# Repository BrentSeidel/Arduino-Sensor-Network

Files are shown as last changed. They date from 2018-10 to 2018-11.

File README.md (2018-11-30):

# Arduino Sensor Network
This repository contains software for a RS-485 based network of Arduinos reporting sensor
values.  A BeagleBone Black is connected to the RS-485 network and collects the data to
be presented was web pages.

Right now, the repository contains software and schematics/wiring diagrams.  It will be updated to also include
OpenSCAD models of parts for 3D printing, parts lists, and wiring diagrams.

## Contents
The contents are divided up into several directories as described below.

### Analyzer
This is Arduino software that just listens to the RS-485 bus and sends the contents back
to the host PC via USB.  It is occasionally useful when debugging to see what is really
on the RS-485 bus.

### Controller
This is Arduino software that polls the other Arduinos on the RS-485 bus.  There should be
only one of these on the bus.  There are provisions for it to accept some commands from
the BeagleBone Black via discrete inputs.

### Documentation
This contains some documentation for the system.

### Monitor
This is Arduino software for a device that listens to the RS-485 bus and displays output
on an LCD.  It is currently obsolete and not being updated.  It might be useful is some
projects.

### Responder
This is Arduino software for a device that listens to the RS-485 bus and responds with data
from sensors.  Currently a few I2C based sensors are supported.  Discrete and Analog input
can also be added.

### RS-485
This is an Arduino library that handles most of the RS-485 network protocol.  It is used
by all of the other Arduino software and needs to be placed in your Arduino library folder.

### Web
This is Ada code for the web server that runs on the BeagleBone Black.  It is uses my
Ada-Web-Server repository on GitHub.

### Schematics
This is a collection of schematics created using KiCAD that are intended to provide assistance
for wiring up various components.

## Dependancies
Some of the items in this repository depend on other repositories.  In particular:
* Web depends on Ada-Web-Server and BBS-Embed-Ada, both of which also depend on  BBS-Ada.

## License
This software is licensed under GPL V3.0.  Should you with to use it with a different
license, please contact the author.

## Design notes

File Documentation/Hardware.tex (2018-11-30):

%\documentclass[10pt, draft]{article}
\documentclass[10pt]{article}

\usepackage{fancyhdr}
\usepackage{multind}
\usepackage{pstricks}
\usepackage{graphicx}
\usepackage[yyyymmdd]{datetime}
\renewcommand{\dateseparator}{-}
\usepackage{geometry}
\geometry{letterpaper}
%
% Front Matter
%
\title{Arduino Sensor Network Documentation -- Hardware}
\author{Brent Seidel \\ Phoenix, AZ}
\date{ \today }
%========================================================
%%% BEGIN DOCUMENT
\begin{document}
\maketitle

\section{Synopsis}
This document contains descriptions of the hardware used in the Arduino Sensor Network.

\section{Network}
The network is based on the RS-485 standard.

\subsection{Topology}
The network uses a daisy-chained topology.  Each end of the chain should have a termination resistor of about 120$\Omega$.  One wire in the pair should have a pull up resistor to V$_{cc}$ and the other wire should have a pull down resistor to Gnd.  This is done at the controller node (see Figure \ref{fig:controller}).

\begin{figure}
  \centering
  
  \caption{Controller Unit}
  \label{fig:controller}
\end{figure}

\subsection{Cabling}
The network cabling uses CAT-5 cables due to its easy availability.  It is not quite optimum for RS-485, but works for this application.  If your application pushes the limits more, you may need another solution.

\subsection{Connectors}
The cables are terminated with DE-9 connectors.  Pins 4 and 8 are used for the bus.  The other pins are avaialble.  Each node has 2 connectors so that the nodes can be daisy chained together.  The cables have male connectors and the nodes have female connectors.  Note that it might be simpler to use RJ45 connectors in your application.

\subsection{Interfacing}
The RS-485 drivers are p/n SN65HVD1781P from Texas Instruments.  Others will probably work, however it may simplify things if the same driver chip is used in all nodes.  It may also help you to get a quantity discount.  Since RS-485 is a differential bus, the drivers have two outputs called `A' and `B' or `+' and `-'.  One side goes high while the other side goes low.  Unfortunately, the labeling isn't completely consistent.  If you use the same driver throughout, you can just make sure that all the `A' sides are connected together and all the `B' sides are connected together.  If you mix drivers, you may need to do a little experimenting to make sure that the proper sides are connected.

\subsection{Baud Rate}
Since there is not a lot of data to transfer, a high baud rate is not necessary.  A higher data rate will put more of a processing load on the nodes and leave less time for them to process their data.  This is a bigger factor for the basic Arduinos.  My application uses 115.2kbps and it seems to work.  An oscilloscope shows that the waveform isn't too distorted.  It also don't put too heavy of a load on the nodes for this particular application.  If more processing is needed in the nodes, a lower baud rate may be needed.

\subsection{Backchannel}
It was decided that it would be useful to be able to send commands from the HTTP gateway (BeagleBone Black) to the controller.  To accomplish this, the TX side of the serial port on the BeagleBone Black and the RX side of one of the extra serial ports on the Arduino Mega 2560 were used.  Since the RS-485 drivers were purchased in bulk, there were some available.  Using these took care of the level shifting (3.3V to 5V) and any needed isolation between the two boards.

\section{Nodes}
There are three basic types of nodes in the network.

\subsection{Responder}
The responder nodes are either Arduino Unos or Boarduinos (an Arduino clone from Adafruit, p/n 72).  See Figure \ref{fig:basic} for an example basic connection of an Arduino Uno to the RS-485 bus and a sensor.  The responder nodes need at least a single serial port and should have an I2C port for interfacing with sensors.  Since the software is for Arduinos, it would need to be ported for any other platform.

\begin{figure}
  \centering
  
  \caption{Basic Arduino Uno Responder Unit with BME280, CCS811, and TSL2561 Sensors}
  \label{fig:basic}
\end{figure}

\subsection{Controller}
The controller is an Arduino Mega 2560.  See Figure \ref{fig:controller} for an example controller node.  Note that the RS-485 interface on the controller contains the pull up and pull down resistors for the A and B wires.  The controller node needs at least two serial ports and possibly other interfaces if it is also to produce data.

\subsection{Web Gateway}
The optional web gateway is a specialized form of listener.  It is based on the BeagleBone Black microcontroller.  See Figure \ref{fig:gateway} for an example web gateway node.  The HTTP gateway needs a serial port and an ethernet port.  The software is written in Ada 2012 and is based on Linux.  Any platform that supports this and has the required ports will probably work.

\begin{figure}
  \centering
  
  \caption{Web Gateway Unit}
  \label{fig:gateway}
\end{figure}

\section{Sensors/Inputs}
The responder nodes can use the discrete I/O pins and the analog input pins.  Custom code is needed to produce the data on the bus.  Software is written for three different I2C based sensors:

\begin{itemize}
  \item BME280 (Adafruit p/n 2652) - This sensor provides calibrated temperature, barometric pressure, and humidity.
  \item TSL2651 (Adafruit p/n 439) - This is a digital light sensor that provides a reading of the light intensity.
  \item CCS811 (Adafruit p/n 3566) - This sensor provides uncalibrated CO$_2$ and Volatile Organic Compound readings.
\end{itemize}

\section{Outputs}
The responder nodes can use the discrete I/O pins as outputs.  Custom code will be needed to set the value of these discretes.  Note that \texttt{LED\_PIN} is by default configured as an output and is controlled by the LSB of the discrete word from the controller.  Software is also provided for the following I2C output device:

\begin{itemize}
  \item PCA9685 (Adafruit p/n 815) - This device is a 6 channel, 12 bit PWM controller.
\end{itemize}

\section{3D Printed Parts}
To be added once 3D models are added to repository.

\section{Miscellaneous}
In addition to the micro controllers, a few of other parts are needed.  The parts for the RS-485 network have already been mentioned.  The sensors needed depend on what you want to do.  Some other parts will be helpful.  A pack of 0.1'' female headers (Adafruit p/n 598) comes in handy when you want to be able to plug and unplug connections.  A set of ``perma-proto'' boads is handy for soldering up simple circuits.  These are also available from Adafruit in various sizes.  I mostly used 1/2 and 1/4 sizes.

\end{document}

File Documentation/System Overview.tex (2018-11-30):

\documentclass[10pt, openany, draft]{article}

\usepackage{fancyhdr}
\usepackage{multind}
\usepackage{pstricks}
\usepackage{graphicx}
\usepackage[yyyymmdd]{datetime}
\renewcommand{\dateseparator}{-}
\usepackage{geometry}
\geometry{letterpaper}
%
% Front Matter
%
\title{Arduino Sensor Network Documentation -- Overview}
\author{Brent Seidel \\ Phoenix, AZ}
\date{ \today }
%========================================================
%%% BEGIN DOCUMENT
\begin{document}
\maketitle
\section{Synopsis}
This document will contain descriptions of the various components of the Arduino Sensor Network.  First is a brief overview of the various components and then a discussion of the communication protocol used between them.  An example network is shown in Figure \ref{fig:Example}.

\begin{figure}
  \centering
  \input{Network}
  \caption{Example Sensor Network}
  \label{fig:Example}
\end{figure}

\section{Components}
The network consists of two required components plus optional components.  The required components are a single controller and one or more responders.  Listeners may optionally be added as they simply monitor the bus traffic and do not transmit.  A BeagleBone Black listener is used to present the data from the network on web pages.  Note that the component boundaries are a little fuzzy in that some components can perform functions from multiple categories.

\subsection{Controller}
The controller is responsible for the operation of the bus.  It sends a request command to each node on the bus and waits for a response.  It may also send data messages.  Typically requests are done in a round-robin fashion -- request node 1, request node 2, etc.  If a node does not respond within a timeout period, it is marked as missing and the next node is polled.

It would probably be possible to combine the controller functions and the web gateway listener function into a BeagleBone Black or other similar embedded computer.  However, keeping them separate allows the controller to be simpler and keep the network functioning even if the web gateway has problems.  So, if presenting data collected on a web page is the primary function of the network, go ahead and combine them.  If, however the primary function of the network is monitoring and controlling something, it would be better to keep the web gateway separate.

\subsection{Responder}
One or more responders may be attached to the bus.  Each responder can produce one or more addresses of data.  The first address (address 0) is used for node identification.  It contains the name and the number of addresses produced by the node.  Additional addresses are produced depending on the sensors attached to the node and the node configuration.

\subsection{Listener}
Any number of listeners may be added to the network.  These simply monitor the network traffic and usually present it in a different format.  A listener can also be used to perform actions based on certain data on the network, though it would probably be better to use a responder that can report back what it is doing.

The BeagleBone Black is used as one example of a listener that presents the data on a web page.  Another example listener is an Arduino that simply listens to the bus and copies the characters to the host computer for display.

\subsection{Web Gateway}
The web gateway is a specialized listener.  It collects data from the bus and presents it as web pages and XML formatted data.  It is uses the \texttt{Ada-Web-Server} repository as the web server.  The RS-485 listener interface is implemented as an Ada Task that receives and processes data from the bus.  The back channel is another Ada Task that is used to transmit commands to the controller.  The use of a task is intended to prevent multiple commands being transmitted simultaneously and getting garbled.

\section{Protocol}
\subsection{Physical Layer}
The physical layer is RS-485 twisted pair.  CAT-5 cable is used because I happen to have a bunch of CAT-5 available and it works.  One pair is used leaving the other pairs available for other uses such as power distribution.  The baud rate is set to 115.2kbps.  This can be changed depending on the application.  The only constraint is that all nodes agree on the baud rate.

\subsection{Node Organization}
Each node is given a unique node ID.  The controller node is given ID 0.  The message format allows 32 bits for the node ID though typically small numbers would be used.  Each node can produce a number of addresses of data.  Address 0 is used to provide node information.  The information includes the number of addresses that the node can produce and the node's name.

\subsection{Messages}
Two types of messages are defined: Requests which only come from the controller and request a specific address of data from a specific node, and Responses which are the data produced by a responder in response to a request.

To aid in debugging, the format of the messages is in ASCII text.  The type of message is indicated by the first character, `\texttt{\@}' for requests and `\texttt{\#}' for responses.  The first two elements in both types of messages is the device ID and the address separated by a forward slash, `\texttt{/}'.  The end of the message is a percent sign, `\texttt{\%}' followed by a (currently unimplemented) checksum and a CR-LF.

All of the numbers are 32 bit unsigned integers expressed in hexadecimal, with leading zeros optional.  

\subsubsection{Requests}
Requests should only be sent by the controller node.  The first character in a request message is an ampersand, `\texttt{\@}'.  This is followed by the device ID in hex, followed by a forward slash, `\texttt{/}'.  Then the address in hex.  The address is optionally followed by a command code and value, each preceded by an apmersand `\texttt{\&}'.  This is followed by a percent sign, `\texttt{\%}' and a currently unused checksum in hex.  The message is terminated by a CR-LF.

If a command code is not specified, the default command code of 0 for \texttt{CMD\_READ} is used.  The currently defined command codes are in Table \ref{tab:commands}.

\begin{table}
  \centering
  \begin{tabular}{c l l}
    \hline
    Value & Symbol & Meaning \\
    \hline
    0 & \texttt{CMD\_READ} & Read data from the specified address.\\
    1 & \texttt{CMD\_RESET} & Perform a software reset.\\
    2 & \texttt{CMD\_WRITE} & Perform an application specific write.\\
  \end{tabular}
  \caption{Defined Command Codes}
  \label{tab:commands}
\end{table}

A typical request looks something like, `\texttt{@00000001/00000000\%FF}'.  This requests address 0 from device 1.  Since leading zeros are optional, the same message can also be expressed as, `\texttt{@1/0\%FF}'.

\subsubsection{Responses}
Responses are sent in response to a request from the controller node.  The first character in a response message is an octathorpe, `\texttt{\#}'.  This is followed by the device ID in hex, the address in hex, and the message type in hex, separated by a forward slash, `\texttt{/}', and ended by an ampersand, `\texttt{\&}'.  This is followed by the data fields.  These are up to 32 32-bit hex numbers separated by apmersands, `\texttt{\&}' and terminated by a percent sign, `\texttt{\%}'.  This is followed by a currently unused checksum in hex.  The message is terminated by a CR-LF.

The format of the responses flexible and the number of data fields sent depends on the type of message.  It may even vary between messages of the same type.  A typical response looks something like \texttt{\#2/1/4\&0\&0\&1E690\&175C0F1\&C775\%FF}.  This is a response from device ID 2, address 1 with message type 4 (\texttt{MSG\_TYPE\_BME280})

If the controller has data to send, it can send a response message without sending a request, as the request can be considered to be implied.

\subsubsection{Message Types}
To make the response messages easier to decode, each message has a message type field.  This indicates what to do with the rest of the data in the message.  Not all messages are currently implemented and more will likely be added.  The various message types are in Table \ref{tab:messagetype}.  Some of the message types have a subtype.  In particular, discretes have the defined types as shown in Table \ref{tab:disctype}, with more likely to be added.  The analog values have the defined types as shown in Table \ref{tab:analogtype}, with more likely to be added.

\begin{table}
  \centering
  \begin{tabular}{r l l}
    \hline
    Value & Symbol & Meaning \\
    \hline
    0 & \texttt{MSG\_TYPE\_UNKNOWN} & Undefined or not present.\\
    1 & \texttt{MSG\_TYPE\_EMPTY} & Everything is OK, but no data to send \\
    2 & \texttt{MSG\_TYPE\_NAK} & Address not supported \\
    3 & \texttt{MSG\_TYPE\_INFO} & Address 0 information message \\
    4 & \texttt{MSG\_TYPE\_BME280} & BME280 sensor values \\
    5 & \texttt{MSG\_TYPE\_DISCRETE} & Discretes \\
    6 & \texttt{MSG\_TYPE\_ANALOG} & Analog values (not yet implemented) \\
    7 & \texttt{MSG\_TYPE\_VERSION} & Version/Software ID (not yet implemented) \\
    8 & \texttt{MSG\_TYPE\_CCS811} & CCS811 sensor values \\
    9 & \texttt{MSG\_TYPE\_TSL2561} & TSL2651 sensor values \\
    10 & \texttt{MSG\_TYPE\_PCA9685} & PCA9685 PWM Controller\\
  \end{tabular}
  \caption{Defined Message Types}
  \label{tab:messagetype}
\end{table}

\begin{table}
  \centering
  \begin{tabular}{c l l}
    \hline
    Value & Symbol & Meaning \\
    \hline
    0 & \texttt{DISCRETE\_UNKNOWN} & Unknown discretes.\\
    1 & \texttt{DISCRETE\_CMD} & Command discretes.\\
    2 & \texttt{DISCRETE\_MIXED} & Mixed discrete types.\\
    3 & \texttt{DISCRETE\_SWITCH} & Discretes from switches.\\
  \end{tabular}
  \caption{Defined Discrete Types}
  \label{tab:disctype}
\end{table}

\begin{table}
  \centering
  \begin{tabular}{c l l}
    \hline
    Value & Symbol & Meaning \\
    \hline
    0 & \texttt{ANALOG\_UNKNOWN} & Unknown analog types.\\
    32 & \texttt{ANALOG\_MIXED} & Mixed analog types.\\
    64 & \texttt{ANALOG\_POT} & Analog values from potentiometers.\\
  \end{tabular}
  \caption{Defined Analog Types}
  \label{tab:analogtype}
\end{table}

\subsection{Back-Channel Commands}
While the commands are human usable, they are designed for ease of parsing, not ease of use.  It is expected that higher level software will provide a wrapper for them.  At this point, they should be considered to be experimental and subject to change.  There are two groups of commands:
\begin{itemize}
  \item General commands tell the controller to do something that applies to all nodes on the network.  The specific general commands currently defined are:
  \begin{itemize}
    \item \texttt{!A} Tell all nodes to turn their indicator LED off.
    \item \texttt{!B} Tell all nodes to turn their indicator LED on.
    \item \texttt{!C} Tell all nodes to toggle their indicator LED.
    \item \texttt{!D} Tell all nodes to identify themselves.
  \end{itemize}
  \item Directed commands are sent to a specific node telling it to do something.  The currently defined directed commands are:
  \begin{itemize}
    \item \texttt{!R<node>,} Request node it node id of \texttt{<node>} to perform a software reset.
    \item \texttt{!S<cmd>,<node>,<arg>,} Send an arbitrary command, \texttt{<cmd>}, to node id \texttt{<node>}, with command arguments, \texttt{<arg>}.
  \end{itemize}
  Where all numbers are in hexidecimal.  Note that the trailing comma is required.
\end{itemize}

\section{Logging}
Data can be logged to files for later analysis.  Provisions exist for logging to be started and stopped and started on a global basis or by record type.  Starting global logging creates the files for the data and stopping global logging closes the files.  To log data, logging has to be started globally and logging of the desired data has to be enabled.  The data records generally supported for logging are:
\begin{itemize}
  \item Node information records
  \item BME280 Temperature, pressure, and humidity sensor
  \item CCS811 eCO$_2$ and TVOC (total volatile organic compounds) air quality sensor
  \item TLS2561 light sensor
\end{itemize}
The discretes and analogs are customized for the application and thus any logging of them would also have to be customized.  The existing logging code can be used as an example.  Note that logging can generate an enormous amount of data, so be prepared.
%======================================
\section{API}
A number of the defined URLs return XML information.  This can be used to create an API that can be used by programs beyond just a web browser.

%---------------------------------------------------------------
\subsection{Graphics}
Two of the URLs return an image in SVG format.  Typically, it is used for display on a web page, but could be used for other purposes.

%---------------------------------------------------------------
\subsubsection{Dial}
The URL is \texttt{/Dial}.  The parameters are:
\begin{itemize}
  \item \texttt{min} - Specify the minimum value shown on the dial (required).
  \item \texttt{max} - Specify the maximum value shown on the dial (required).
  \item \texttt{value} - Specify the value indicated by the dial's pointer (required).
\end{itemize}

%---------------------------------------------------------------
\subsubsection{Thermometer}
The URL is \texttt{/Thermometer}.  The parameters are:
\begin{itemize}
  \item \texttt{min} - Specify the minimum value shown on the thermometer (required).
  \item \texttt{max} - Specify the maximum value shown on the thermometer (required).
  \item \texttt{value} - Specify the value indicated by the thermometer (required).
\end{itemize}

%---------------------------------------------------------------
\subsection{Data and Control}
The rest of the URLs either return data or are used to control the system.  All of these return an XML message containing either requested data or an error message.

%---------------------------------------------------------------
\subsubsection{Send a Command to a Node}
This function is used to send a command to the controller via the back channel.  The URL is \texttt{/xml/Command}.  There is one parameter:
\begin{itemize}
  \item \texttt{command} - The command to send as text (required).
\end{itemize}

The returned data is returned in a \texttt{<xml>} block with the following contents:
\begin{itemize}
  \item \texttt{command} - Echoes the sent command, if the \texttt{command} parameter was present, or
  \item \texttt{error} - Provides an error message if the \texttt{command} parameter was not present.
\end{itemize}

%---------------------------------------------------------------
\subsubsection{Get System Counters}
The URL is \texttt{/xml/Counter}.  There are no parameters.  The returned data is in a \texttt{<xml>} block with the following contents:
\begin{itemize}
  \item \texttt{<counter>} - XML container for number of web requests handled counter.
  \item \texttt{<tasks>} - XML contained for number of currently active web handler tasks.
  \item \texttt{<rs485>} - XML container for RS-485 state machine activity counter.
\end{itemize}

%---------------------------------------------------------------
\subsubsection{Get Maximum Device Number on the Network}
The URL is \texttt{/xml/Devices}.  There are no parameters.  The returned data is in a \texttt{<xml>} block with the following contents:
\begin{itemize}
  \item \texttt{<length>} - XML container for the maximum device number found on the network.  Used to set the length of data structures.
\end{itemize}

%---------------------------------------------------------------
\subsubsection{Get Data from a Device on the Network}
While this call is simple, this returns the most complex set of data.  The URL is \texttt{/xml/DevData}.  There is one parameter:
\begin{itemize}
  \item \texttt{device} - Contains the node ID of the device to get data from (required).
\end{itemize}

The returned data is in an \texttt{<xml>} block.  The following components may, or may not be present depending on the configuration of the node:
\begin{itemize}
  \item \texttt{<info>} - This should always be present.
  \begin{itemize}
    \item \texttt{<validity>} - Validity status for info data.
    \item \texttt{<aging>} - Number of seconds since info message received.
    \item \texttt{<addresses>} - Number of addresses supported by device.
    \item \texttt{<name>} - Name of the node.
  \end{itemize}
  \item \texttt{<bme280>} - Present if node is configured with a BME280 sensor.
  \begin{itemize}
    \item \texttt{<validity>} - Validity status for BME280 data.
    \item \texttt{<aging>} - Number of seconds since BME280 message received.
    \item \texttt{<bme280\_status>} - Status of the BME280 sensor reported by node.
    \item \texttt{<bme280\_age>} - Number of frames since BME280 sensor data read.
    \item \texttt{<bme280\_temp\_c>} - Temperature in degrees Celcius.
    \item \texttt{<bme280\_pressure\_pa>} - Atmospheric pressure in Pascals.
    \item \texttt{<bme280\_humidity>} - Relative humidity in percent.
  \end{itemize}
  \item \texttt{<discretes>} - Present if node is configured to transmit discretes.
  \begin{itemize}
    \item \texttt{<validity>} - Validity status for discretes data.
    \item \texttt{<aging>} - Number of seconds since discretes message received.
    \item \texttt{<disc\_type>} - Code indicating the type of these discretes.
    \item \texttt{<disc\_value>} - Value of the discretes as a 32 bit unsigned integer.  One bit for each discrete.
  \end{itemize}
  \item \texttt{<analogs>} - Present if node is configured to transmit analog values.
  \begin{itemize}
    \item \texttt{<validity>} - Validity status for analog data.
    \item \texttt{<aging>} - Number of seconds since analog message received.
    \item \texttt{<analog\_type>} - Code indicating the type of these analog values.
    \item \texttt{<analog\_count>} - The number of analog value provided in this message.
    \item \texttt{<value>} - Value of analog reading.  This entry is repeated \texttt{analog\_count} times.  Once for each analog value.
  \end{itemize}
  \item \texttt{<ccs811>} - Present if node is configured with a CCS811 sensor.
  \begin{itemize}
    \item \texttt{<validity>} - Validity status for CCS811 data.
    \item \texttt{<aging>} - Number of seconds since CCS811 message received.
    \item \texttt{<ccs811\_status>} - Status of the CCS811 sensor reported by node.
    \item \texttt{<ccs811\_age>} - Number of frames since CCS811 sensor data read.
    \item \texttt{<ccs811\_eco2>} - Measurement of CO$_2$ concentration.
    \item \texttt{<ccs811\_tvoc>} - Measurement of total volatile organic compounds (TVOC) concentration.
  \end{itemize}
  \item \texttt{<tsl2561>} - Present if node is configured with a TSL2561 sensor.
  \begin{itemize}
    \item \texttt{<validity>} - Validity status for TSL2561 data.
    \item \texttt{<aging>} - Number of seconds since TSL2561 message received.
    \item \texttt{<tsl2561\_status>} - Status of the TSL2561 sensor reported by node.
    \item \texttt{<tsl2561\_age>} - Number of frames since TSL2561 sensor data read.
    \item \texttt{<tsl2561\_data0>} - Measurement of one band of light.
    \item \texttt{<tsl2561\_data1>} - Measurement of one band of light.
    \item \texttt{<tsl2561\_lux>} - Calculated illumination in Lux.
  \end{itemize}
  \item \texttt{<pca9685>} - Present if node is configured with a PCA9685 PWM controller.
  \begin{itemize}
    \item \texttt{<validity>} - Validity status for PCA9685 data.
    \item \texttt{<aging>} - Number of seconds since PCA9685 message received.
    \item \texttt{<channel>} - One of these entries for each of the 16 PWM channels.  Each entry contains three comma separated values.  The values are:
    \begin{itemize}
      \item A boolean indicating if this channel has been set.
      \item An unsigned integer indicating the PWM ``On'' count.
      \item An unsigned integer indicating the PWM ``Off'' count.
    \end{itemize}
  \end{itemize}
  \item \texttt{<error>} - Present if an error has occurred.
\end{itemize}

%---------------------------------------------------------------
\subsubsection{Control Debugging Messages}
Various debugging messages can be displayed on the console.  This entry can be used to turn messages on or off and to report the status of debugging messages.  The URL is \texttt{/xml/Debug}.  There are several parameters:
\begin{itemize}
  \item \texttt{rs485.char} - Set to `T' to print characters that are read from the RS-485 bus (optional).
  \item \texttt{rs485.msg} - Set to `T' to print the type of message that is read from the RS-485 bus (optional).
  \item \texttt{http.head} - Set to `T' to print the headers from each HTTP request (optional).
  \item \texttt{http.msg} - Set to `T' to print the HTTP requests (optional).
  \item \texttt{web.dbg} - Set to `T' to print debugging messages from the web server (optional).
\end{itemize}

The returned data is in a \texttt{<xml>} block with the following contents:
\begin{itemize}
  \item \texttt{<rs485.char>} - \texttt{TRUE} if RS-485 character debugging is enabled.
  \item \texttt{<rs485.msg>} - \texttt{TRUE} if RS-485 message debugging is enabled.
  \item \texttt{<http.head>} - \texttt{TRUE} if HTTP header debugging is enabled.
  \item \texttt{<http.msg>} - \texttt{TRUE} if HTTP request debugging is enabled.
  \item \texttt{<web.dbg>} - \texttt{TRUE} if web debugging is enabled.
\end{itemize}

%---------------------------------------------------------------
\subsubsection{Control Data Logging}
Starting logging is a two step process.  First the specific messages to log need to be enabled.  Then logging needs to be turned on.  The URL is \texttt{/xml/Log}.  There are several parameters:
\begin{itemize}
  \item \texttt{log.info} - Set to `T' to enable logging of info messages (optional).
  \item \texttt{log.BME280} - Set to `T' to enable logging of BME280 messages (optional).
  \item \texttt{log.CCS811} - Set to `T' to enable logging of CCS811 messages (optional).
  \item \texttt{log.TSL2561} - Set to `T' to enable logging of TSL2561 messages (optional).
  \item \texttt{logging} - Set to `T' to turn logging on (optional).
\end{itemize}

The returned data is in a \texttt{<xml>} block with the following contents:
\begin{itemize}
  \item \texttt{<log.info>} - \texttt{TRUE} if info message logging is enabled.
  \item \texttt{<log.BME280>} - \texttt{TRUE} if BME280 message logging is enabled.
  \item \texttt{<log.CCS811>} - \texttt{TRUE} if CCS811 message logging is enabled.
  \item \texttt{<log.TSL2561>} - \texttt{TRUE} if TSL2561 message logging is enabled.
  \item \texttt{<log.type>} - Set to the type of log files.  Currently either \texttt{NONE} or \texttt{CSV}.
\end{itemize}

%---------------------------------------------------------------
\subsubsection{Get Device Name}
The URL is \texttt{/xml/Name} name internal.  There is one parameter:
\begin{itemize}
  \item \texttt{device} - Specify the device number to get information from (required).
\end{itemize}

The returned data is in a \texttt{<xml>} block with the following contents:
\begin{itemize}
  \item \texttt{<info>} - Block containing device information, if present.  The information consists of the following:
  \begin{itemize}
    \item \texttt{<validity>} - Validity code for the data.
    \item \texttt{<aging>} - The time in seconds since the info record was received from the node.
    \item \texttt{<presence>} - The time in seconds since any records were received from the node.
    \item \texttt{<addresses>} - The number of addresses supported by the node.
    \item \texttt{<name>} - The node's name as a string.
  \end{itemize}
  \item \texttt{<error>} - Block containing an error message if device information cannot be provided.
\end{itemize}

\end{document}

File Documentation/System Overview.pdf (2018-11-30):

### Arduino Sensor Network Documentation – Overview

Brent Seidel
Phoenix, AZ

2018-11-25

## 1 Synopsis

This document will contain descriptions of the various components of the Arduino Sensor Network. First is a brief overview of the various components and then a discussion of the communication protocol used between them. An example network is shown in Figure 1.

## 2 Components

The network consists of two required components plus optional components. The required components are a single controller and one or more responders. Listeners may optionally be added as they simply monitor the bus traffic and do not transmit. A BeagleBone Black listener is used to present the data from the network on web pages. Note that the component boundaries are a little fuzzy in that some components can perform functions from multiple categories.

### 2.1 Controller

The controller is responsible for the operation of the bus. It sends a request command to each node on the bus and waits for a response. It may also send data messages. Typically requests are done in a round-robin fashion – request node 1, request node 2, etc. If a node does not respond within a timeout period, it is marked as missing and the next node is polled.
It would probably be possible to combine the controller functions and the web gateway listener function into a BeagleBone Black or other similar embedded computer. However, keeping them separate allows the controller to be simpler and keep the network functioning even if the web gateway has problems. So, if presenting data collected on a web page is the primary function of the network, go ahead and combine them. If, however the primary function of the network is monitoring and controlling something, it would be better to keep the web gateway separate.

### 2.2 Responder

One or more responders may be attached to the bus. Each responder can produce one or more addresses of data. The first address (address 0) is used for node identification. It contains the name and the number of addresses produced by the node. Additional addresses are produced depending on the sensors attached to the node and the node configuration.

1

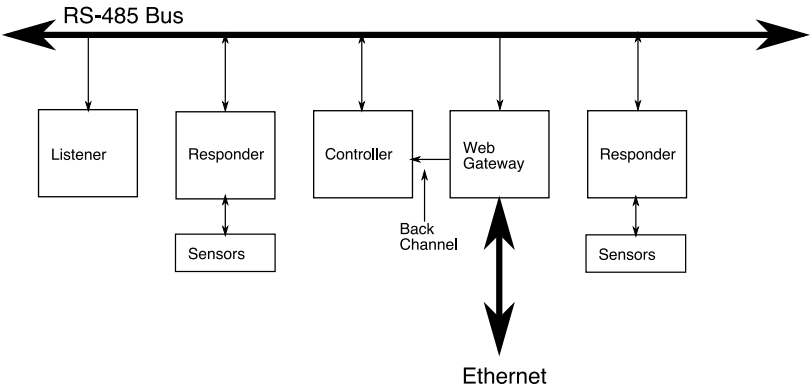
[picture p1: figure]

Figure 1: Example Sensor Network

### 2.3 Listener

Any number of listeners may be added to the network. These simply monitor the network traffic and usually present it in a different format. A listener can also be used to perform actions based on certain data on the network, though it would probably be better to use a responder that can report back what it is doing.
The BeagleBone Black is used as one example of a listener that presents the data on a web page. Another example listener is an Arduino that simply listens to the bus and copies the characters to the host computer for display.

### 2.4 Web Gateway

The web gateway is a specialized listener. It collects data from the bus and presents it as web pages and XML formatted data. It is uses the Ada-Web-Server repository as the web server. The RS-485 listener interface is implemented as an Ada Task that receives and processes data from the bus. The back channel is another Ada Task that is used to transmit commands to the controller. The use of a task is intended to prevent multiple commands being transmitted simultaneously and getting garbled.

## 3 Protocol

### 3.1 Physical Layer

The physical layer is RS-485 twisted pair. CAT-5 cable is used because I happen to have a bunch of CAT-5 available and it works. One pair is used leaving the other pairs available for other uses such as power distribution. The baud rate is set to 115.2kbps. This can be changed depending on the application. The only constraint is that all nodes agree on the baud rate.

2

Value Symbol | Meaning
0 | CMD READ | Read data from the specified address.
1 | CMD RESET | Perform a software reset.
2 | CMD WRITE | Perform an application specific write.

Table 1: Defined Command Codes

### 3.2 Node Organization

Each node is given a unique node ID. The controller node is given ID 0. The message format allows 32 bits for the node ID though typically small numbers would be used. Each node can produce a number of addresses of data. Address 0 is used to provide node information. The information includes the number of addresses that the node can produce and the node’s name.

### 3.3 Messages

Two types of messages are defined: Requests which only come from the controller and request a specific address of data from a specific node, and Responses which are the data produced by a responder in response to a request.
To aid in debugging, the format of the messages is in ASCII text. The type of message is indicated by the first character, ‘’ for requests and ‘#’ for responses. The first two elements in both types of messages is the device ID and the address separated by a forward slash, ‘/’. The end of the message is a percent sign, ‘%’ followed by a (currently unimplemented) checksum and a CR-LF. All of the numbers are 32 bit unsigned integers expressed in hexadecimal, with leading zeros optional.

### 3.3.1 Requests

Requests should only be sent by the controller node. The first character in a request message is an ampersand, ‘’. This is followed by the device ID in hex, followed by a forward slash, ‘/’. Then the address in hex. The address is optionally followed by a command code and value, each preceded by an apmersand ‘&’. This is followed by a percent sign, ‘%’ and a currently unused checksum in hex. The message is terminated by a CR-LF.
If a command code is not specified, the default command code of 0 for CMD READ is used. The currently defined command codes are in Table 1.
A typical request looks something like, ‘@00000001/00000000%FF’. This requests address 0 from device 1. Since leading zeros are optional, the same message can also be expressed as, ‘@1/0%FF’.

### 3.3.2 Responses

Responses are sent in response to a request from the controller node. The first character in a response message is an octathorpe, ‘#’. This is followed by the device ID in hex, the address in hex, and the message type in hex, separated by a forward slash, ‘/’, and ended by an ampersand, ‘&’. This is followed by the data fields. These are up to 32 32-bit hex numbers separated by apmersands, ‘&’ and terminated by a percent sign, ‘%’. This is followed by a currently unused checksum in hex. The message is terminated by a CR-LF.

3

Value Symbol | Meaning
0 MSG TYPE UNKNOWN | Undefined or not present.
1 MSG TYPE EMPTY | Everything is OK, but no data to send
2 MSG TYPE NAK | Address not supported
3 MSG TYPE INFO | Address 0 information message
4 MSG TYPE BME280 | BME280 sensor values
5 MSG TYPE DISCRETE | Discretes
6 MSG TYPE ANALOG | Analog values (not yet implemented)
7 MSG TYPE VERSION | Version/Software ID (not yet implemented)
8 MSG TYPE CCS811 | CCS811 sensor values
9 MSG TYPE TSL2561 | TSL2651 sensor values
10 MSG TYPE PCA9685 | PCA9685 PWM Controller

Table 2: Defined Message Types

Value Symbol | Meaning
0 | DISCRETE UNKNOWN | Unknown discretes.
1 | DISCRETE CMD | Command discretes.
2 | DISCRETE MIXED | Mixed discrete types.
3 | DISCRETE SWITCH | Discretes from switches.

Table 3: Defined Discrete Types

The format of the responses flexible and the number of data fields sent depends on the type of message. It may even vary between messages of the same type. A typical response looks something like #2/1/4&0&0&1E690&175C0F1&C775%FF. This is a response from device ID 2, address 1 with message type 4 (MSG TYPE BME280)
If the controller has data to send, it can send a response message without sending a request, as the request can be considered to be implied.

### 3.3.3 Message Types

To make the response messages easier to decode, each message has a message type field. This indicates what to do with the rest of the data in the message. Not all messages are currently implemented and more will likely be added. The various message types are in Table 2. Some of the message types have a subtype. In particular, discretes have the defined types as shown in Table 3, with more likely to be added. The analog values have the defined types as shown in Table 4, with more likely to be added.

Value Symbol | Meaning
0 | ANALOG UNKNOWN | Unknown analog types.
32 | ANALOG MIXED | Mixed analog types.
64 | ANALOG POT | Analog values from potentiometers.

Table 4: Defined Analog Types

4

### 3.4 Back-Channel Commands

While the commands are human usable, they are designed for ease of parsing, not ease of use. It is expected that higher level software will provide a wrapper for them. At this point, they should be considered to be experimental and subject to change. There are two groups of commands:

- General commands tell the controller to do something that applies to all nodes on the network. The specific general commands currently defined are:

– !A Tell all nodes to turn their indicator LED off.
– !B Tell all nodes to turn their indicator LED on.
– !C Tell all nodes to toggle their indicator LED.
– !D Tell all nodes to identify themselves.
- Directed commands are sent to a specific node telling it to do something. The currently defined directed commands are:

– !R<node>, Request node it node id of <node> to perform a software reset.
– !S<cmd>,<node>,<arg>, Send an arbitrary command, <cmd>, to node id <node>, with command arguments, <arg>.

Where all numbers are in hexidecimal. Note that the trailing comma is required.

## 4 Logging

Data can be logged to files for later analysis. Provisions exist for logging to be started and stopped and started on a global basis or by record type. Starting global logging creates the files for the data and stopping global logging closes the files. To log data, logging has to be started globally and logging of the desired data has to be enabled. The data records generally supported for logging are:

- Node information records
- BME280 Temperature, pressure, and humidity sensor
- CCS811 eCO2 and TVOC (total volatile organic compounds) air quality sensor
- TLS2561 light sensor

The discretes and analogs are customized for the application and thus any logging of them would also have to be customized. The existing logging code can be used as an example. Note that logging can generate an enormous amount of data, so be prepared.

## 5 API

A number of the defined URLs return XML information. This can be used to create an API that can be used by programs beyond just a web browser.

5

### 5.1 Graphics

Two of the URLs return an image in SVG format. Typically, it is used for display on a web page, but could be used for other purposes.

### 5.1.1 Dial

The URL is /Dial. The parameters are:

- min - Specify the minimum value shown on the dial (required).
- max - Specify the maximum value shown on the dial (required).
- value - Specify the value indicated by the dial’s pointer (required).

### 5.1.2 Thermometer

The URL is /Thermometer. The parameters are:

- min - Specify the minimum value shown on the thermometer (required).
- max - Specify the maximum value shown on the thermometer (required).
- value - Specify the value indicated by the thermometer (required).

### 5.2 Data and Control

The rest of the URLs either return data or are used to control the system. All of these return an XML message containing either requested data or an error message.

### 5.2.1 Send a Command to a Node

This function is used to send a command to the controller via the back channel. The URL is /xml/Command. There is one parameter:

- command - The command to send as text (required).

The returned data is returned in a <xml> block with the following contents:

- command - Echoes the sent command, if the command parameter was present, or
- error - Provides an error message if the command parameter was not present.

### 5.2.2 Get System Counters

The URL is /xml/Counter. There are no parameters. The returned data is in a <xml> block with the following contents:

- <counter> - XML container for number of web requests handled counter.
- <tasks> - XML contained for number of currently active web handler tasks.
- <rs485> - XML container for RS-485 state machine activity counter.

6

### 5.2.3 Get Maximum Device Number on the Network

The URL is /xml/Devices. There are no parameters. The returned data is in a <xml> block with the following contents:

- <length> - XML container for the maximum device number found on the network. Used to set the length of data structures.

### 5.2.4 Get Data from a Device on the Network

While this call is simple, this returns the most complex set of data. The URL is /xml/DevData. There is one parameter:

- device - Contains the node ID of the device to get data from (required).

The returned data is in an <xml> block. The following components may, or may not be present depending on the configuration of the node:

- <info> - This should always be present.

– <validity> - Validity status for info data.
– <aging> - Number of seconds since info message received. – <addresses> - Number of addresses supported by device. – <name> - Name of the node.
- <bme280> - Present if node is configured with a BME280 sensor.

– <validity> - Validity status for BME280 data.
– <aging> - Number of seconds since BME280 message received.
– <bme280 status> - Status of the BME280 sensor reported by node. – <bme280 age> - Number of frames since BME280 sensor data read. – <bme280 temp c> - Temperature in degrees Celcius.
– <bme280 pressure pa> - Atmospheric pressure in Pascals.
– <bme280 humidity> - Relative humidity in percent.
- <discretes> - Present if node is configured to transmit discretes.

– <validity> - Validity status for discretes data.
– <aging> - Number of seconds since discretes message received.
– <disc type> - Code indicating the type of these discretes.
– <disc value> - Value of the discretes as a 32 bit unsigned integer. One bit for each discrete.
- <analogs> - Present if node is configured to transmit analog values.

– <validity> - Validity status for analog data.
– <aging> - Number of seconds since analog message received.

7

– <analog type> - Code indicating the type of these analog values.
– <analog count> - The number of analog value provided in this message.
– <value> - Value of analog reading. This entry is repeated analog count times. Once for each analog value.
- <ccs811> - Present if node is configured with a CCS811 sensor.

– <validity> - Validity status for CCS811 data.
– <aging> - Number of seconds since CCS811 message received.
– <ccs811 status> - Status of the CCS811 sensor reported by node.
– <ccs811 age> - Number of frames since CCS811 sensor data read.
– <ccs811 eco2> - Measurement of CO2 concentration.
– <ccs811 tvoc> - Measurement of total volatile organic compounds (TVOC) concentration.
- <tsl2561> - Present if node is configured with a TSL2561 sensor.

– <validity> - Validity status for TSL2561 data.
– <aging> - Number of seconds since TSL2561 message received.
– <tsl2561 status> - Status of the TSL2561 sensor reported by node. – <tsl2561 age> - Number of frames since TSL2561 sensor data read. – <tsl2561 data0> - Measurement of one band of light.
– <tsl2561 data1> - Measurement of one band of light.
– <tsl2561 lux> - Calculated illumination in Lux.
- <pca9685> - Present if node is configured with a PCA9685 PWM controller.

– <validity> - Validity status for PCA9685 data.
– <aging> - Number of seconds since PCA9685 message received.
– <channel> - One of these entries for each of the 16 PWM channels. Each entry contains three comma separated values. The values are:
∗ A boolean indicating if this channel has been set.
∗ An unsigned integer indicating the PWM “On” count.
∗ An unsigned integer indicating the PWM “Off” count.
- <error> - Present if an error has occurred.

### 5.2.5 Control Debugging Messages

Various debugging messages can be displayed on the console. This entry can be used to turn messages on or off and to report the status of debugging messages. The URL is /xml/Debug. There are several parameters:

- rs485.char - Set to ‘T’ to print characters that are read from the RS-485 bus (optional).

8

- rs485.msg - Set to ‘T’ to print the type of message that is read from the RS-485 bus (optional).
- http.head - Set to ‘T’ to print the headers from each HTTP request (optional).
- http.msg - Set to ‘T’ to print the HTTP requests (optional).
- web.dbg - Set to ‘T’ to print debugging messages from the web server (optional).

The returned data is in a <xml> block with the following contents:

- <rs485.char> - TRUE if RS-485 character debugging is enabled.
- <rs485.msg> - TRUE if RS-485 message debugging is enabled.
- <http.head> - TRUE if HTTP header debugging is enabled.
- <http.msg> - TRUE if HTTP request debugging is enabled.
- <web.dbg> - TRUE if web debugging is enabled.

### 5.2.6 Control Data Logging

Starting logging is a two step process. First the specific messages to log need to be enabled. Then logging needs to be turned on. The URL is /xml/Log. There are several parameters:

- log.info - Set to ‘T’ to enable logging of info messages (optional).
- log.BME280 - Set to ‘T’ to enable logging of BME280 messages (optional).
- log.CCS811 - Set to ‘T’ to enable logging of CCS811 messages (optional).
- log.TSL2561 - Set to ‘T’ to enable logging of TSL2561 messages (optional).
- logging - Set to ‘T’ to turn logging on (optional).

The returned data is in a <xml> block with the following contents:

- <log.info> - TRUE if info message logging is enabled.
- <log.BME280> - TRUE if BME280 message logging is enabled.
- <log.CCS811> - TRUE if CCS811 message logging is enabled.
- <log.TSL2561> - TRUE if TSL2561 message logging is enabled.
- <log.type> - Set to the type of log files. Currently either NONE or CSV.

9

### 5.2.7 Get Device Name

The URL is /xml/Name name internal. There is one parameter:

- device - Specify the device number to get information from (required).

The returned data is in a <xml> block with the following contents:

- <info> - Block containing device information, if present. The information consists of the following:

– <validity> - Validity code for the data.
– <aging> - The time in seconds since the info record was received from the node.
– <presence> - The time in seconds since any records were received from the node. – <addresses> - The number of addresses supported by the node.
– <name> - The node’s name as a string.
- <error> - Block containing an error message if device information cannot be provided.

10

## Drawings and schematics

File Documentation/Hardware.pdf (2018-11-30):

# Arduino Sensor Network Documentation – Hardware

Brent Seidel
Phoenix, AZ

2018-11-26

## 1 Synopsis

This document contains descriptions of the hardware used in the Arduino Sensor Network.

## 2 Network

The network is based on the RS-485 standard.

### 2.1 Topology

The network uses a daisy-chained topology. Each end of the chain should have a termination resistor of about 120Ω. One wire in the pair should have a pull up resistor to Vcc and the other wire should have a pull down resistor to Gnd. This is done at the controller node (see Figure 1).

### 2.2 Cabling

The network cabling uses CAT-5 cables due to its easy availability. It is not quite optimum for RS-485, but works for this application. If your application pushes the limits more, you may need another solution.

### 2.3 Connectors

The cables are terminated with DE-9 connectors. Pins 4 and 8 are used for the bus. The other pins are avaialble. Each node has 2 connectors so that the nodes can be daisy chained together. The cables have male connectors and the nodes have female connectors. Note that it might be simpler to use RJ45 connectors in your application.

### 2.4 Interfacing

The RS-485 drivers are p/n SN65HVD1781P from Texas Instruments. Others will probably work, however it may simplify things if the same driver chip is used in all nodes. It may also help you to get a quantity discount. Since RS-485 is a differential bus, the drivers have two outputs called ‘A’ and ‘B’ or ‘+’ and ‘-’. One side goes high while the other side goes low. Unfortunately, the labeling isn’t completely consistent. If you use the same driver throughout, you can just make sure that all

1

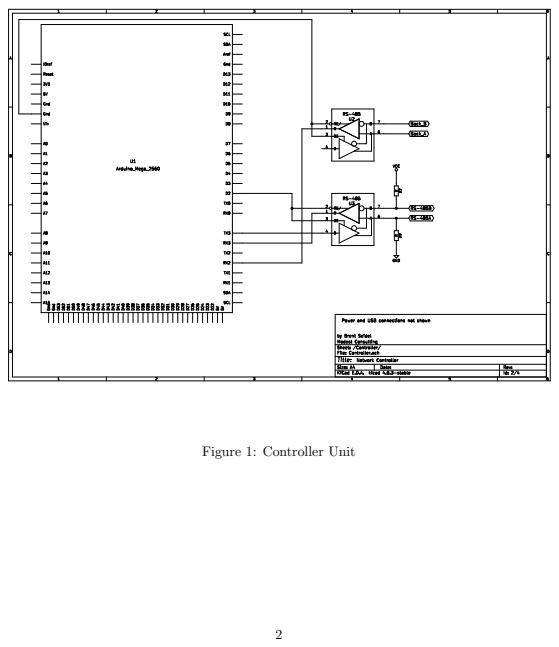
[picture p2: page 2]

Figure 1: Controller Unit

the ‘A’ sides are connected together and all the ‘B’ sides are connected together. If you mix drivers, you may need to do a little experimenting to make sure that the proper sides are connected.

### 2.5 Baud Rate

Since there is not a lot of data to transfer, a high baud rate is not necessary. A higher data rate will put more of a processing load on the nodes and leave less time for them to process their data. This is a bigger factor for the basic Arduinos. My application uses 115.2kbps and it seems to work. An oscilloscope shows that the waveform isn’t too distorted. It also don’t put too heavy of a load on the nodes for this particular application. If more processing is needed in the nodes, a lower baud rate may be needed.

### 2.6 Backchannel

It was decided that it would be useful to be able to send commands from the HTTP gateway (BeagleBone Black) to the controller. To accomplish this, the TX side of the serial port on the BeagleBone Black and the RX side of one of the extra serial ports on the Arduino Mega 2560 were used. Since the RS-485 drivers were purchased in bulk, there were some available. Using these took care of the level shifting (3.3V to 5V) and any needed isolation between the two boards.

## 3 Nodes

There are three basic types of nodes in the network.

### 3.1 Responder

The responder nodes are either Arduino Unos or Boarduinos (an Arduino clone from Adafruit, p/n 72). See Figure 2 for an example basic connection of an Arduino Uno to the RS-485 bus and a sensor. The responder nodes need at least a single serial port and should have an I2C port for interfacing with sensors. Since the software is for Arduinos, it would need to be ported for any other platform.

### 3.2 Controller

The controller is an Arduino Mega 2560. See Figure 1 for an example controller node. Note that the RS-485 interface on the controller contains the pull up and pull down resistors for the A and B wires. The controller node needs at least two serial ports and possibly other interfaces if it is also to produce data.

### 3.3 Web Gateway

The optional web gateway is a specialized form of listener. It is based on the BeagleBone Black microcontroller. See Figure 3 for an example web gateway node. The HTTP gateway needs a serial port and an ethernet port. The software is written in Ada 2012 and is based on Linux. Any platform that supports this and has the required ports will probably work.

3

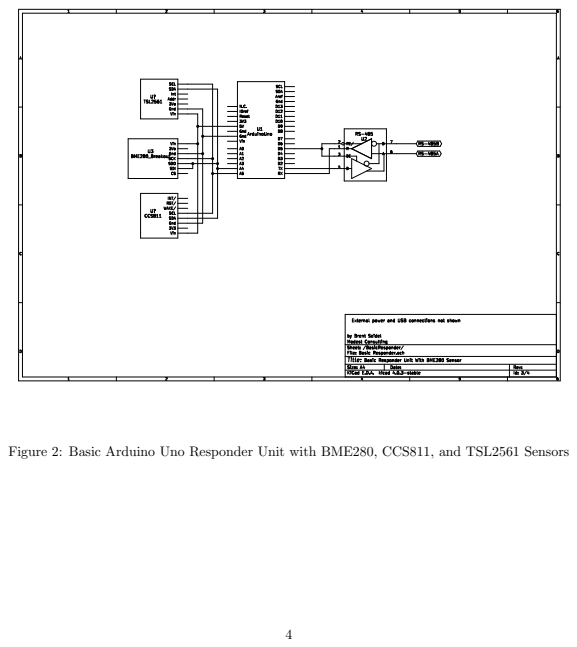
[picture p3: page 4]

Figure 2: Basic Arduino Uno Responder Unit with BME280, CCS811, and TSL2561 Sensors

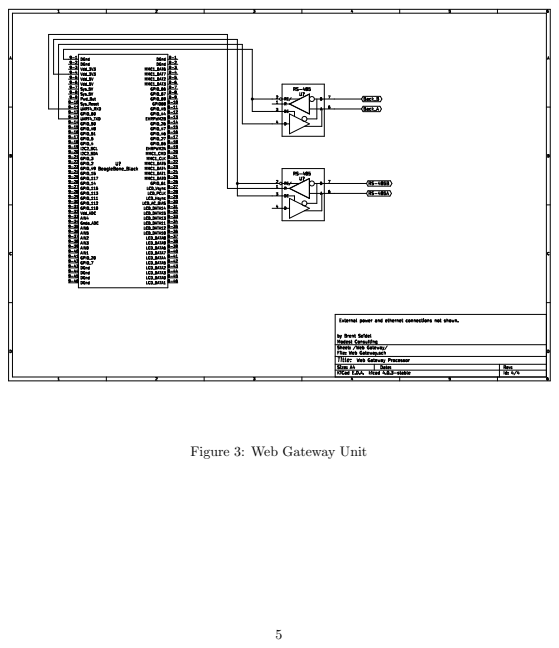
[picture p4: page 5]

Figure 3: Web Gateway Unit
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

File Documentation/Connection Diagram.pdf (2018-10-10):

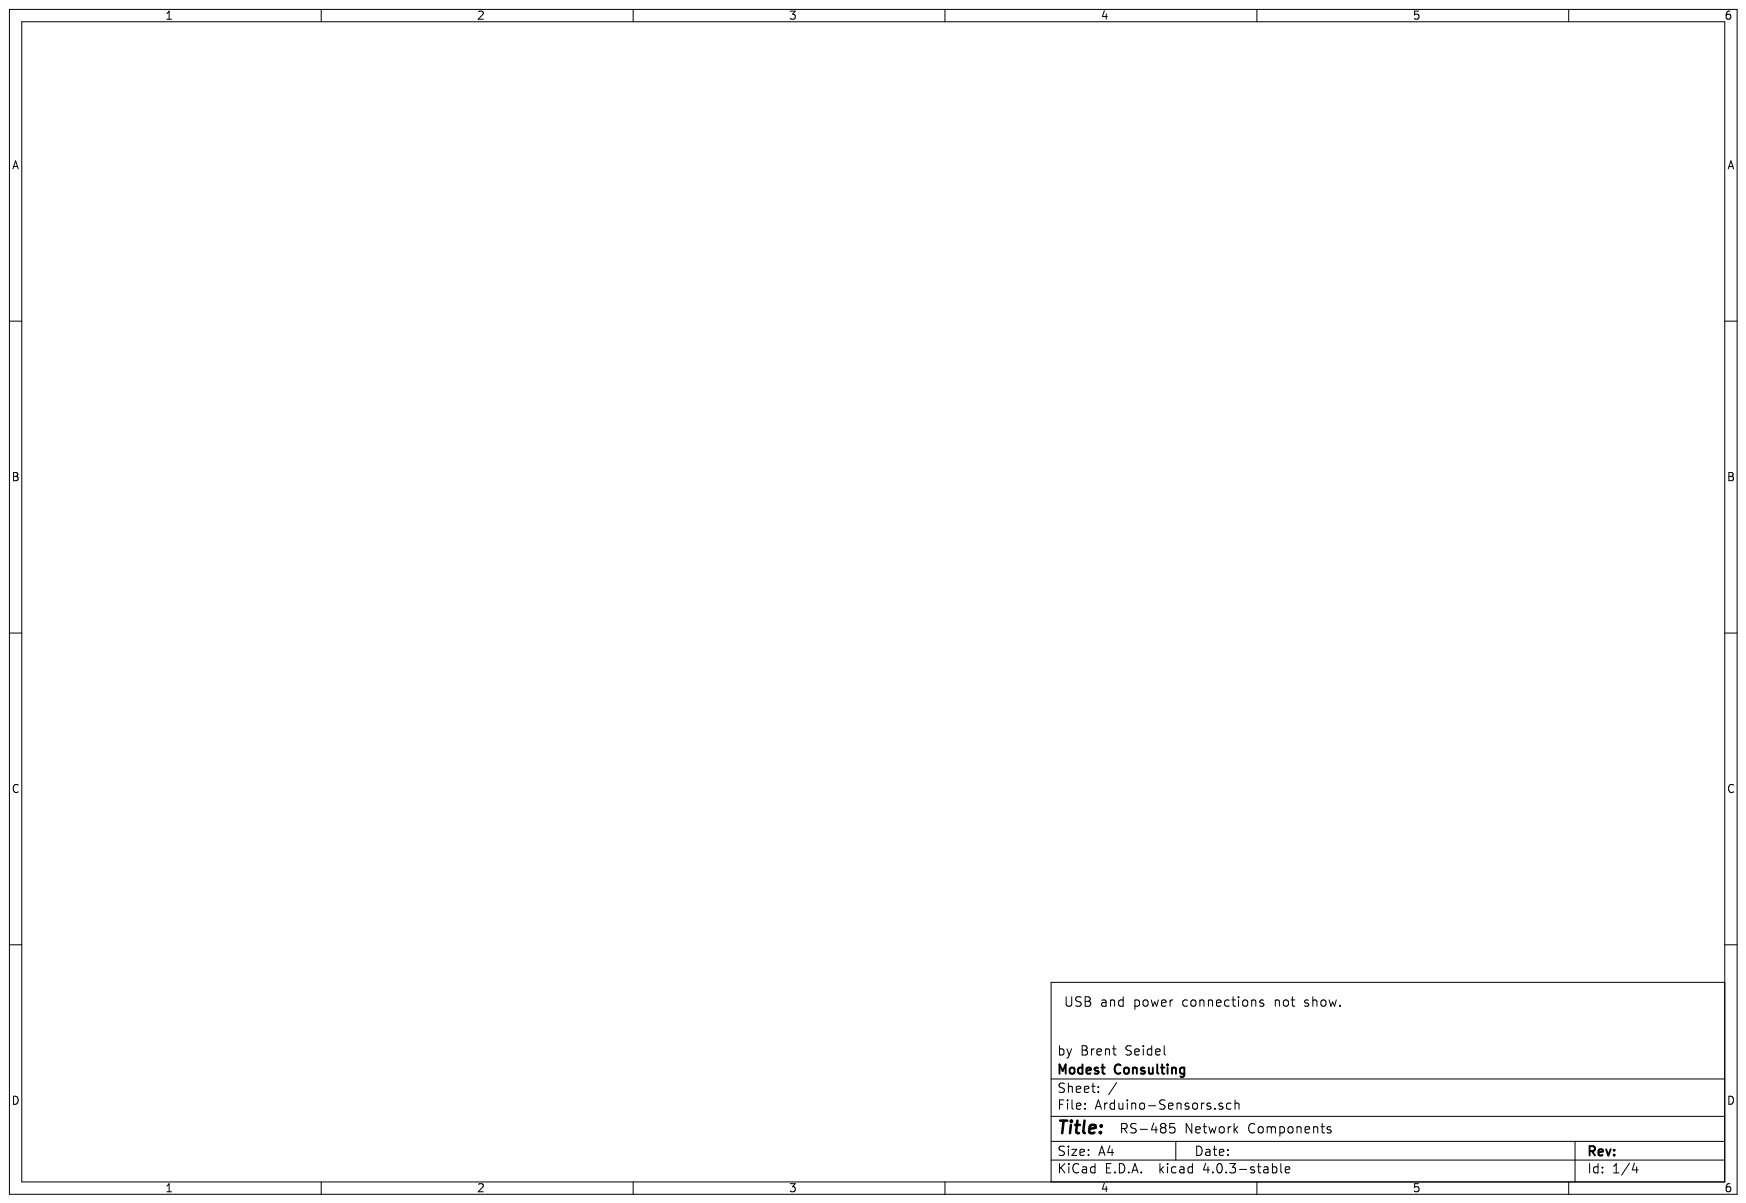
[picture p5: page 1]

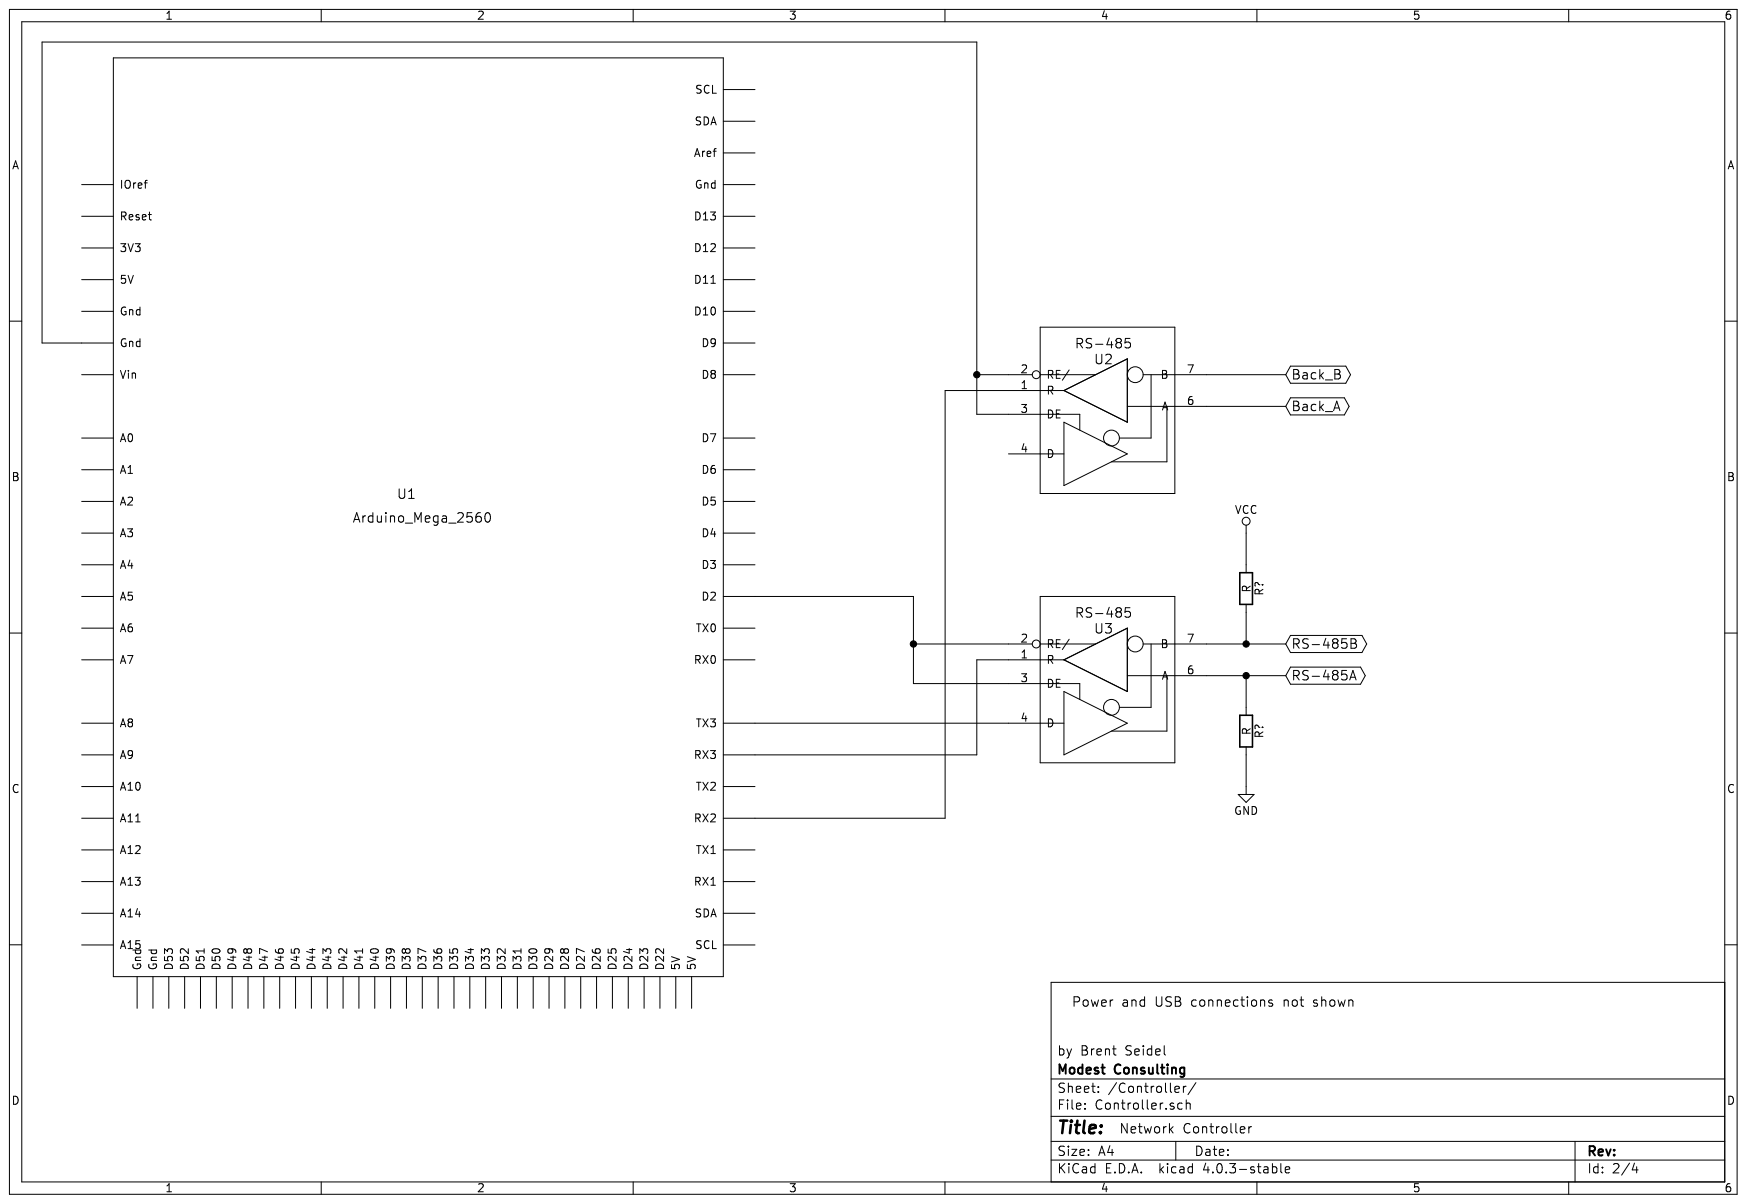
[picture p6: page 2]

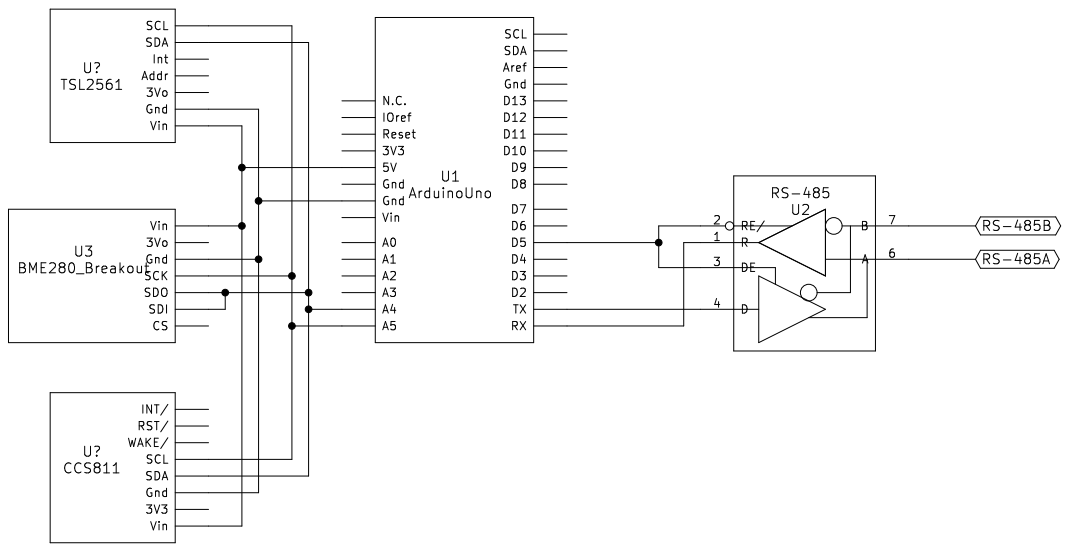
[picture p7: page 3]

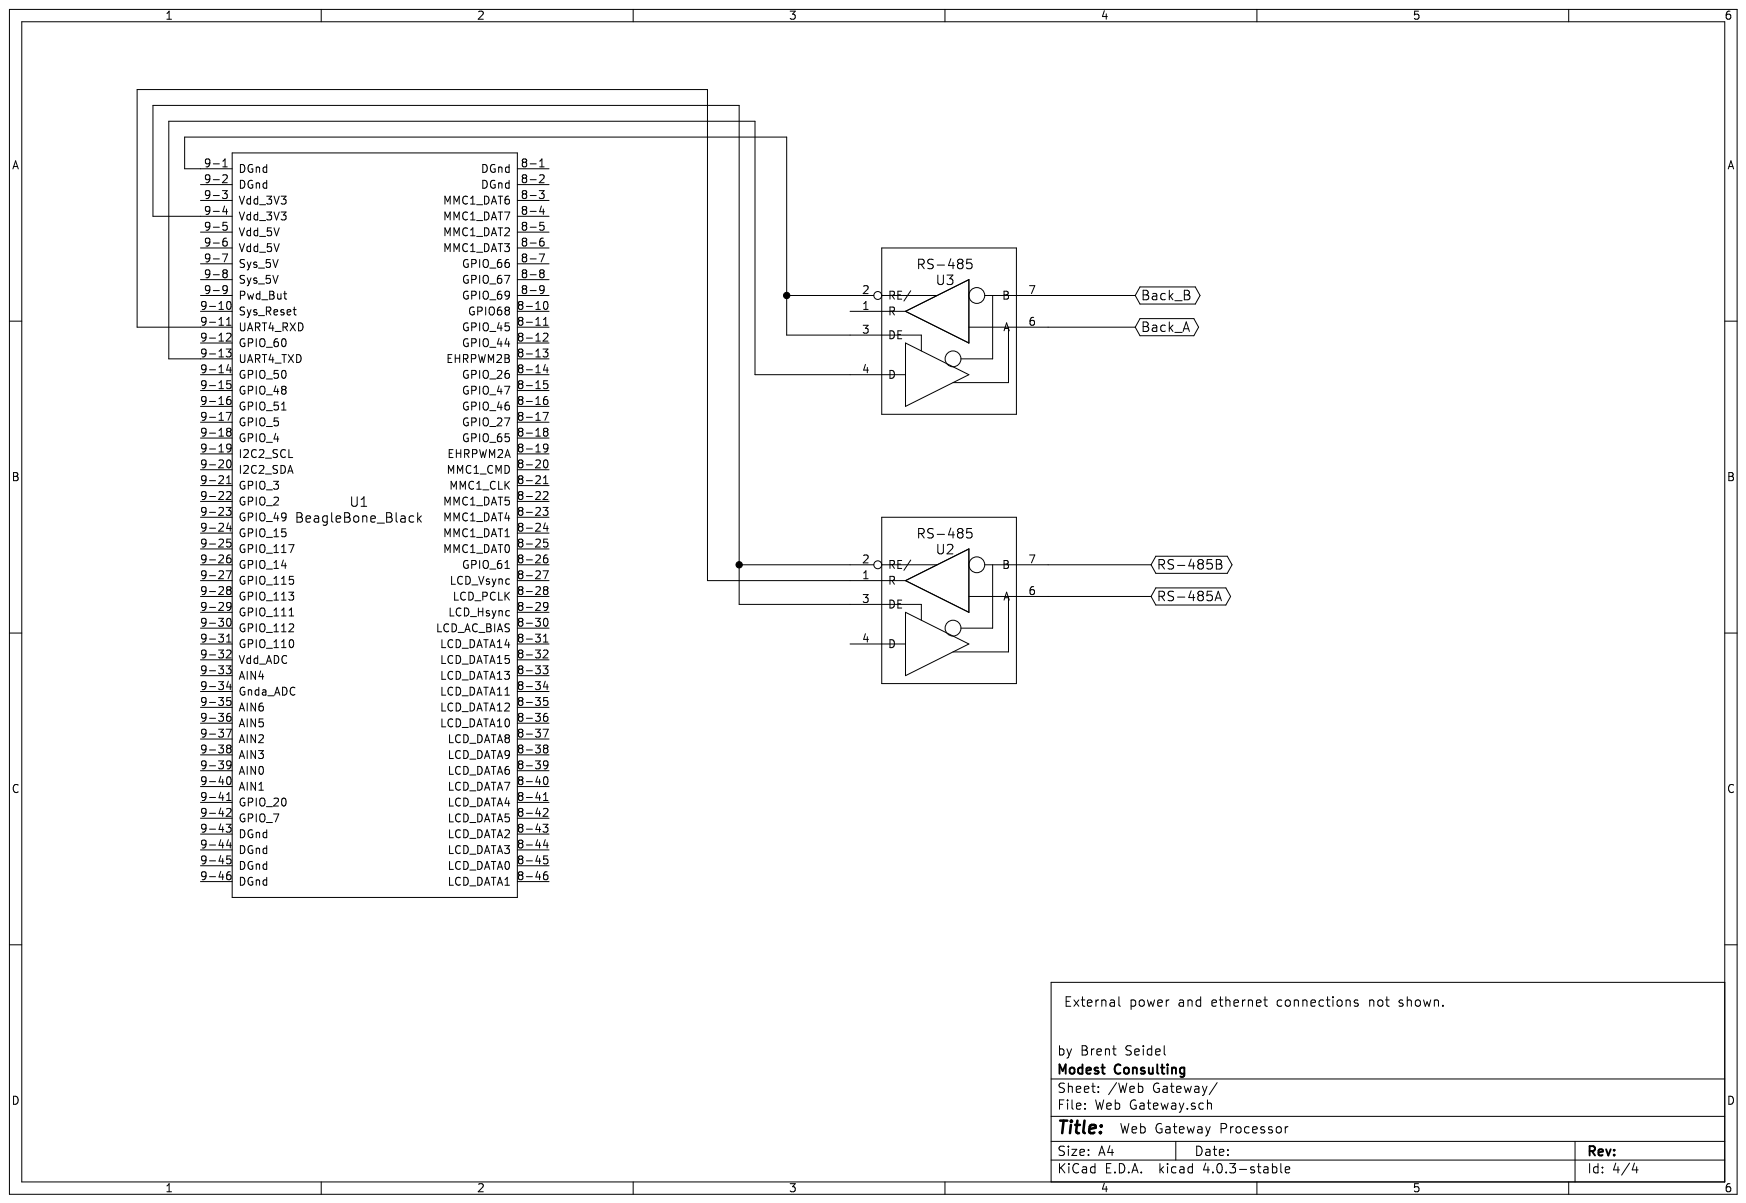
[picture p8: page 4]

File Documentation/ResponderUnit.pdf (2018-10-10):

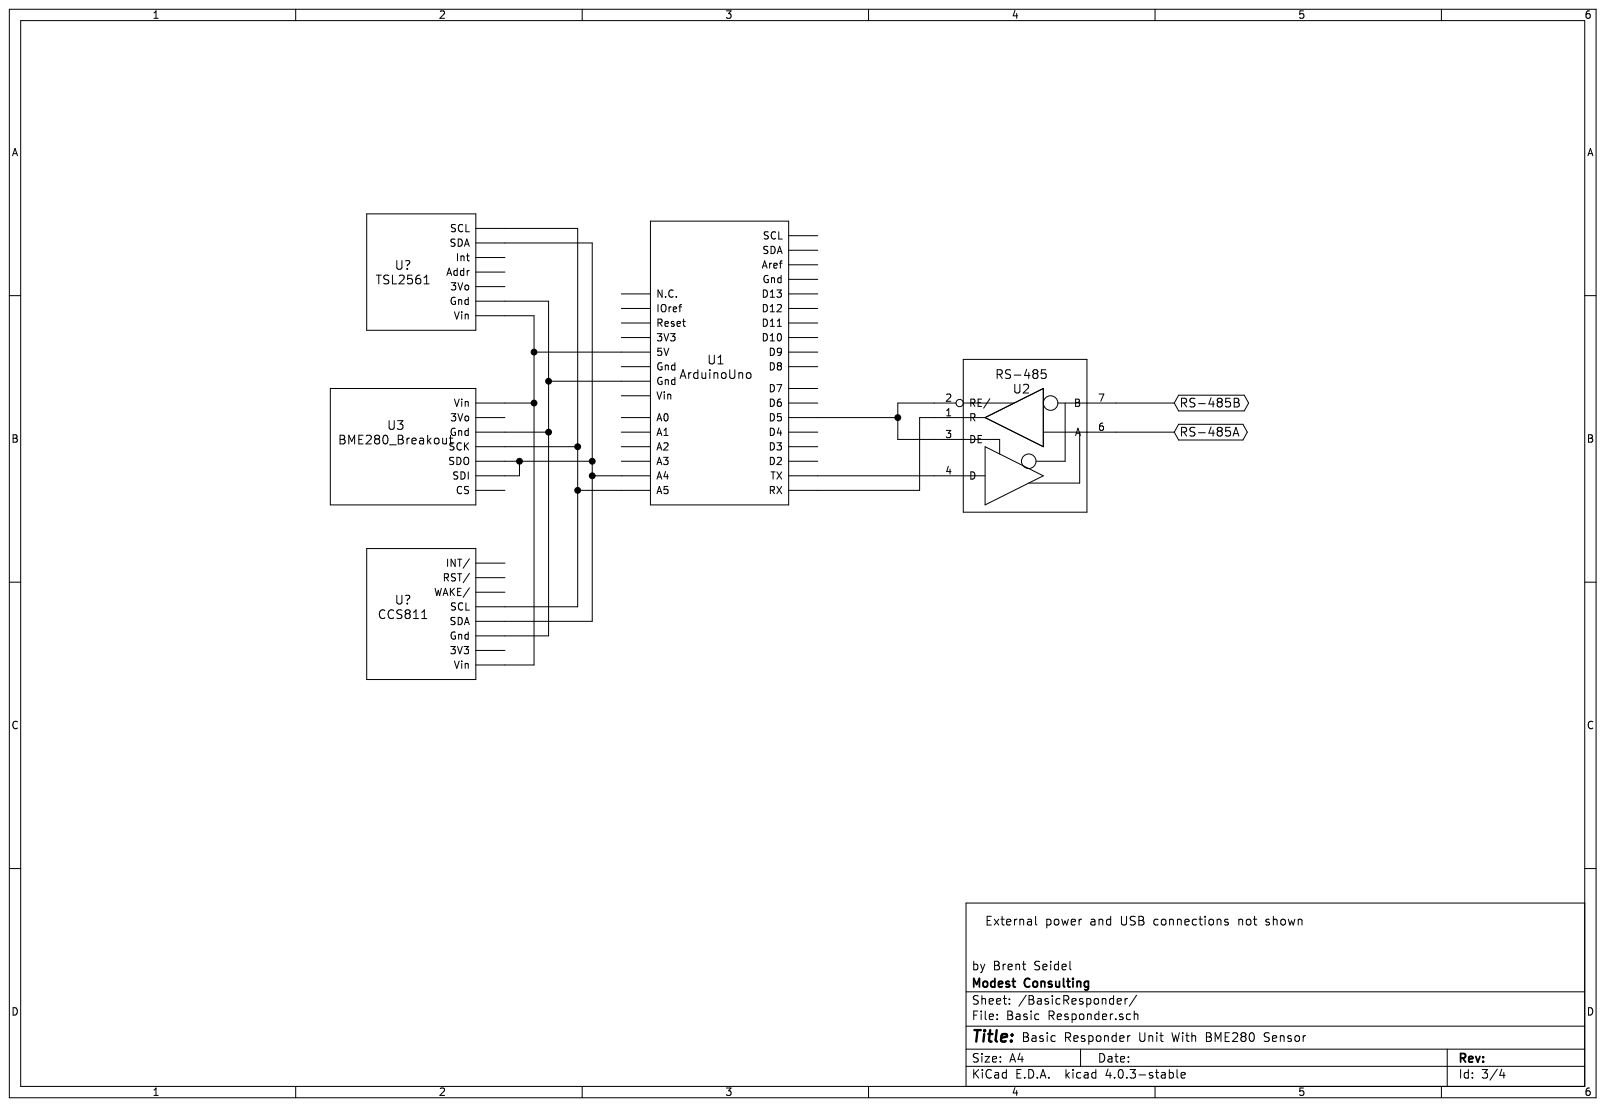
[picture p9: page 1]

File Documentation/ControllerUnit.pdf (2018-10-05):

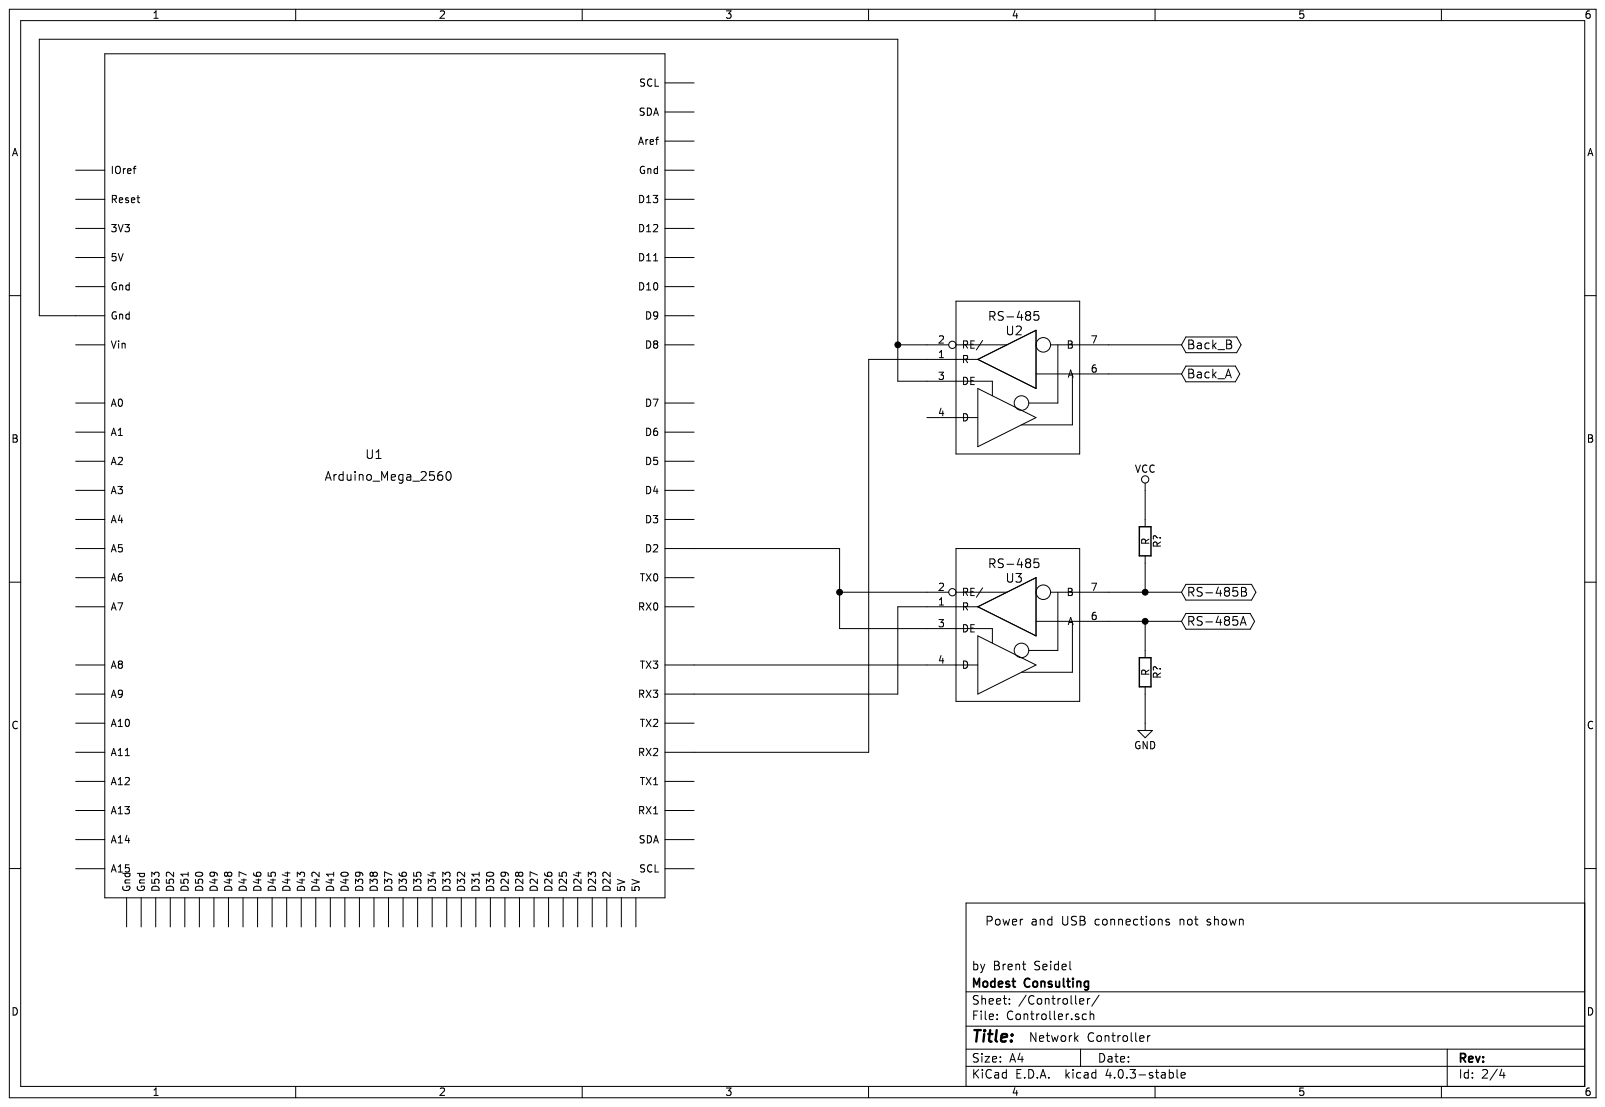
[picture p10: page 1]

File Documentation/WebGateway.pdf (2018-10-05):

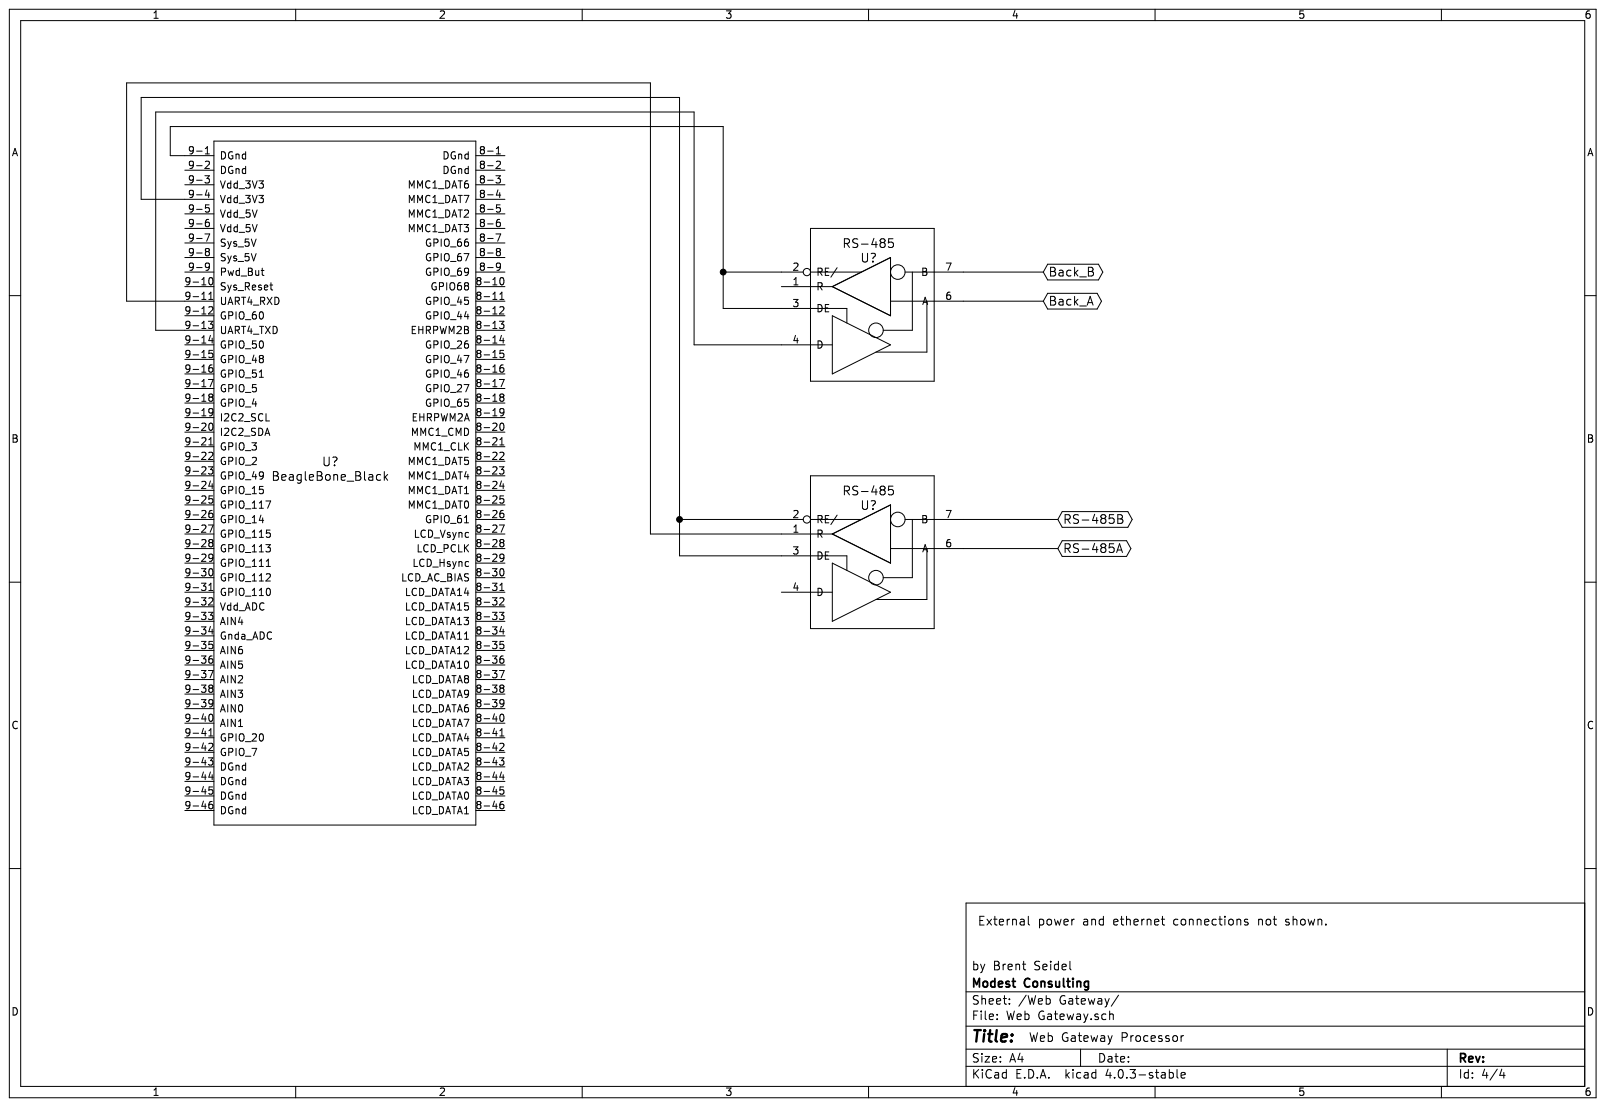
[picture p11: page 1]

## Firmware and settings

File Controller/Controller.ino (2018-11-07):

#include <RS-485.h>
//
// pin 7 - Switch input
// pin 6 - Switch input
// pin 5 - RS-485 direction output
//
//
// Change this to whichever port is hooked up to RS-485.  For the Uno, use the only
// serial port.  For the Mega and Due, use Serial3
//
// To allow commands from a BeagleBone Black, a Mega or Due is required.  In this case,
// the main RS-485 network is on Serial3 and the commands are input on Serial2.
//
#if defined (__AVR_ATmega328P__)
HardwareSerial *rs485 = &Serial;
#define RS485_TX_COMPLETE (SERIAL0_TX_COMPLETE)
#else
HardwareSerial *rs485 = &Serial3;
#define RS485_TX_COMPLETE (SERIAL3_TX_COMPLETE)
#endif
const int TX_RX = 2; // Pin 2 is used to control direction.
//
// The following two pins are used to generate signals that are useful for triggering
// an oscilloscope or other such device.
//
const int CMD_PIN = 23; // Set high while a command is being sent
const int MSG_PIN = 22; // Set high while a message is being sent
//
extern int get_hex_digit(int data);

//
// States
// 0 - Sending command
// 1 - Waiting for transmission to complete
// 2 - Waiting for '\r' indicating end of reply.
//
const uint8_t STATE_START = 0;
const uint8_t STATE_WAIT_TX = 12;
const uint8_t STATE_WAIT_RX = 13;
uint8_t state = STATE_START;
//
// Command definitions for general commands.  Directed commands are defined in the
// rs485.h header file.
//
const uint8_t CMD_NULL = 0;       // Do nothing special
const uint8_t CMD_LED_OFF = 1;    // Command all sensors to turn their LED off
const uint8_t CMD_LED_ON = 2;     // Command all sensors to turn their LED on
const uint8_t CMD_LED_TOGGLE = 3; // Command all sensors to toggle their LED (default case)
const uint8_t CMD_ID = 4;         // Request ID from all sensor units
//
//  Command states
//
const uint8_t CMD_STATE_START = 0;
const uint8_t CMD_STATE_CMD = 1;
const uint8_t CMD_STATE_GET_CMD = 2;
const uint8_t CMD_STATE_GET_NODE = 3;
const uint8_t CMD_STATE_GET_ARG = 4;
const uint8_t CMD_STATE_DONE = 5;
uint8_t read_cmd();
struct cmd_state_type
{
  uint8_t state;
  uint32_t cmd;
  uint32_t args;
  uint32_t node;
  boolean directed;
  boolean need_node;
  boolean need_cmd;
  boolean need_arg;
};
cmd_state_type cmd_data = {.state = CMD_STATE_START};
struct directed_cmd_type
{
  uint32_t cmd;
  uint32_t arg;
};
directed_cmd_type directed_cmd[NUM_NODES];
//
// Delays
//
#define XMIT_DELAY 1
#define TIMEOUT_DELAY 500
//
// Device ID and name
//
// Controller node ID (this node).  Controller is always node 0.
//
#define CTRL_NODE 0
//
// Name must be 32 characters padded with spaces on the end.
//                  12345678901234567890123456789012
const char* name = "Control, not KAOS               ";
//
uint32_t disc_value = 0;
//
// Supported number of nodes on network
//
int node_state[NUM_NODES];
int max_addr[NUM_NODES];
unsigned int max_node = 7;
unsigned int timeout_delay = TIMEOUT_DELAY;
unsigned long end_time;
unsigned int node_id = NUM_NODES;

const bool DEBUG = true;

void setup()
{
  int x;

  rs485->begin(BAUD_RATE);
  Serial2.begin(BAUD_RATE);
  Serial.begin(BAUD_RATE);
  pinMode(TX_RX, OUTPUT);  // RS-485 direction control
  pinMode(CMD_PIN, OUTPUT);
  pinMode(MSG_PIN, OUTPUT);
  for (x = 0; x < NUM_NODES; x++)
  {
    node_state[x] = 0;
    max_addr[x] = 0;
    directed_cmd[x].cmd = CMD_NULL;
    directed_cmd[x].arg = 0;
  }
}

void loop()
{
  int x;
  int data;
  uint8_t reply_state;
  uint8_t command;
  static uint8_t led_state = 0;
  static uint8_t led_command = CMD_LED_OFF;
//
// Process commands coming in on the discretes.
//
  switch (read_cmd())
  {
    case CMD_LED_OFF:
      led_command = CMD_LED_OFF;
      led_state = 0;
      break;
    case CMD_LED_ON:
      led_command = CMD_LED_ON;
      led_state = 1;
      break;
    case CMD_LED_TOGGLE:
      led_command = CMD_LED_TOGGLE;
      break;
    case CMD_ID:
      for (x = 0; x < NUM_NODES; x++)
      {
        node_state[x] = 0;
        max_addr[x] = 0;
      }
      break;
    default:
      break;
  }
//
// Main state machine
//
  switch (state)
  {
    case STATE_START:
      node_id++;
      if (node_id > max_node)
      {
        node_id = CTRL_NODE;
      }
      delay(XMIT_DELAY);
      if (node_id == CTRL_NODE)
      {
        Serial.println("Control node transmission");
      }
//      else
//      {
//        Serial.print("Requesting device ");
//        Serial.print(node_id, DEC);
//        Serial.print(" address ");
//        Serial.println(node_state[node_id]);
//      }
      digitalWrite(TX_RX, HIGH);  // Prepare to transmit
      if (node_id == CTRL_NODE)
      {
        digitalWrite(MSG_PIN, HIGH);
        if (node_state[CTRL_NODE] == 0)
        {
          rs485_msg_info(rs485, CTRL_NODE, 0, 1, name);
        }
        else
        {
          if (led_command == CMD_LED_TOGGLE)
          {
            led_state++;
            led_state = led_state % 2;
          }
          rs485_msg_disc(rs485, CTRL_NODE, 1, DISCRETE_CMD, disc_value*2 + led_state);
          //
          // For test purposes, just increment the discrete value.
          //
          disc_value++;
        }
        digitalWrite(MSG_PIN, LOW);
        node_state[CTRL_NODE] = 1;
      }
      else
      {
        if (directed_cmd[node_id].cmd == CMD_READ)
        {
//          Serial.print("Requesting read of node ");
//          Serial.println(node_id, DEC);
          digitalWrite(CMD_PIN, HIGH);
          rs485->print("@");
          rs485->print(node_id, HEX);
          rs485->print("/");
          rs485->print(node_state[node_id], HEX);
          rs485->println("%FF");
          digitalWrite(CMD_PIN, LOW);
        }
        else
        {
          Serial.print("Directed command to node ");
          Serial.println(node_id, DEC);
          digitalWrite(CMD_PIN, HIGH);
          rs485->print("@");
          rs485->print(node_id, HEX);
          rs485->print("/");
          rs485->print(node_state[node_id], HEX);
          rs485->print("&");
          rs485->print(directed_cmd[node_id].cmd, HEX);
          rs485->print("&");
          rs485->print(directed_cmd[node_id].arg, HEX);
          rs485->println("%FF");
          digitalWrite(CMD_PIN, LOW);
          directed_cmd[node_id].cmd = CMD_READ;
          directed_cmd[node_id].arg = 0;
        }
      }
      state = STATE_WAIT_TX;
      break;
    case STATE_WAIT_TX: // Wait for transmission to complete
      if (RS485_TX_COMPLETE)
      {
        digitalWrite(TX_RX, LOW);  // End transmission
        if (node_id == 0)
        {
          state = STATE_START; // There is no response to the message from the controller
        }
        else
        {
          state = STATE_WAIT_RX;
          end_time = millis() + TIMEOUT_DELAY; // Compute timeout value
        }
      }
      break;
    case STATE_WAIT_RX: // Wait for response or timemout
      reply_state = rs485_state_machine(rs485, &Serial, false);
      if (reply_state == STATE_RS485_GOT_MSG)
      {
//        Serial.print("Got reply from node ");
//        Serial.println(device, DEC);
        if (device == node_id)
        {
          if  (address == 0)
          {
            max_addr[node_id] = data_buffer[0];
          }
          node_state[node_id]++;
          if (node_state[node_id] > max_addr[node_id])
          {
            node_state[node_id] = 1;
          }
        }
        else
        {
          Serial.print("Node ");
          Serial.print(device, DEC);
          Serial.print(" responded, expected node ");
          Serial.println(node_id, DEC);
        }
        delay(5); // A little delay to wait for sender to release the bus
        state = STATE_START;
      }
      //
      // The timeout test here will need to be updated to account for wraparound
      // of the timer.
      //
      if (millis() > end_time)
      {
        node_state[node_id] = 0;
        state = STATE_START;
      }
      break;
    default:
      break;
  }
}
//
// This function processes commands received from the web gateway unit.  Two types of commands
// are available - general commands and directed commands.  General commands apply to all units
// on the network.  Directed commands are directed towards one particular node.
//
uint8_t read_cmd()
{
  int data = Serial2.read();
  uint8_t command = CMD_NULL;
  int     temp;

  if (data > 0)
  {
    switch (cmd_data.state)
    {
      case CMD_STATE_START:
        if (data == '!')
        {
          cmd_data.state = CMD_STATE_CMD;
        }
        cmd_data.cmd = CMD_NULL;
        cmd_data.args = 0;
        cmd_data.node = 0;
        cmd_data.directed = false;
        cmd_data.need_node = false;
        cmd_data.need_cmd = false;
        cmd_data.need_arg = false;
        break;
      case CMD_STATE_CMD:
        switch (data)
        {
          case 'A':
            Serial.println("Command LED Off");
            cmd_data.cmd = CMD_LED_OFF;
            cmd_data.state = CMD_STATE_DONE;
            break;
          case 'B':
            Serial.println("Command LED On");
            cmd_data.cmd = CMD_LED_ON;
            cmd_data.state = CMD_STATE_DONE;
            break;
          case 'C':
            Serial.println("Command LED Toggle");
            cmd_data.cmd = CMD_LED_TOGGLE;
            cmd_data.state = CMD_STATE_DONE;
            break;
          case 'D':
            Serial.println("Command Identify");
            cmd_data.cmd = CMD_ID;
            cmd_data.state = CMD_STATE_DONE;
            break;
          case 'R':
            Serial.println("Directed reset command");
            cmd_data.cmd = CMD_RESET;
            cmd_data.state = CMD_STATE_GET_NODE;
            cmd_data.directed = true;
            cmd_data.need_node = true;
            break;
          case 'S':
            Serial.println("Directed arbitrary command");
            cmd_data.state = CMD_STATE_GET_CMD;
            cmd_data.directed = true;
            cmd_data.need_node = true;
            cmd_data.need_arg = true;
            break;
          default:
            cmd_data.state = CMD_STATE_START;
            break;
        }
        break;
      case CMD_STATE_GET_CMD:
//        Serial.println("State get command.");
        temp = get_hex_digit(data);
        if (temp >= 0)
        {
          cmd_data.cmd = cmd_data.cmd*0x10 + temp;
        }
        else
        {
          if ((data == ',') && (cmd_data.need_node))
          {
            cmd_data.state = CMD_STATE_GET_NODE;
          }
          else if ((data == ',') && (cmd_data.need_arg)) 
          {
            cmd_data.state = CMD_STATE_GET_ARG;
          }
          else if (data == ',')
          {
            cmd_data.state = CMD_STATE_DONE;
          }
          else
          {
            cmd_data.state = CMD_STATE_START;
          }
        }
        break;
      case CMD_STATE_GET_NODE:
//        Serial.println("State get node.");
        temp = get_hex_digit(data);
        if (temp >= 0)
        {
          cmd_data.node = cmd_data.node*0x10 + temp;
        }
        else
        {
          if ((data == ',') && (cmd_data.need_arg)) 
          {
            cmd_data.state = CMD_STATE_GET_ARG;
          }
          else if (data == ',')
          {
            cmd_data.state = CMD_STATE_DONE;
          }
          else
          {
            cmd_data.state = CMD_STATE_START;
          }
        }
        break;
      case CMD_STATE_GET_ARG:
//        Serial.println("State get arg.");
        temp = get_hex_digit(data);
        if (temp >= 0)
        {
          cmd_data.args = cmd_data.args*0x10 + temp;
        }
        else
        {
          if (data == ',')
          {
            cmd_data.state = CMD_STATE_DONE;
          }
          else
          {
            cmd_data.state = CMD_STATE_START;
          }
        }
        break;
      case CMD_STATE_DONE:
//        Serial.println("State done.");
        cmd_data.state = CMD_STATE_START;
        if (cmd_data.directed)
        {
          Serial.print("Sending directed command ");
          Serial.print(cmd_data.cmd, DEC);
          Serial.print(" to node ");
          Serial.print(cmd_data.node, DEC);
          Serial.print(" with arguments ");
          Serial.println(cmd_data.args, DEC);
          if ((cmd_data.node > 0) && (cmd_data.node < NUM_NODES))
          {
            directed_cmd[cmd_data.node].cmd = cmd_data.cmd;
            directed_cmd[cmd_data.node].arg = cmd_data.args;
          }
        }
        else
        {
          command = cmd_data.cmd;
        }
        break;
      default:
        cmd_data.state = CMD_STATE_START;
        break;
    }
    Serial.write(data);
  }
  return command;
}

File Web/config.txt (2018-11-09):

#
# Configuration file for Ada web server
#
# HTML pages
#
/ index.html text/html
/Main index.html text/html
/Settings settings.html text/html
/Form form.html text/html
/Dashboard dashboard.html text/html
#
# Internal pages
#
/Config configure internal
/Form_Target target internal
/Thermometer thermometer internal
/Dial dial internal
/Devices devices internal
/ConfigReload reload internal
#
# Plain text
#
/list config.txt text/plain
/Proc/Status /proc/self/status text/plain
#
# JavaScript
#
/SetJS settings.js application/javascript
/DashJS dashboard.js application/javascript
#
# Images
#
# There are no images right now.
#
# XML stuff
#
/xml/Command send-command internal
/xml/Counter counter internal
/xml/Devices device-count internal
/xml/Name name internal
/xml/DevData device-data internal
/xml/Debug debugging internal
/xml/Log logging internal
#
# Style sheet for pages.
#
/Style table.css text/css
#
# Some comments at the end of the file.
#

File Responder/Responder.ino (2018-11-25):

#include <RS-485.h>
#include <Wire.h>
//
// Display debugging messages?  If set true, the node should either be an Arduino
// Mega 2560 (or similar with multiple serial ports) or disconnected from the network.
// On the basic Arduino the RS485 and the debug serial port are shared.
//
const bool DEBUG = false;
//
// Pick which serial device to use for the RS-485 interface.
//
#if defined (__AVR_ATmega328P__)
HardwareSerial *rs485 = &Serial;
#define RS485_TX_COMPLETE (SERIAL0_TX_COMPLETE)
#else
HardwareSerial *rs485 = &Serial3;
#define RS485_TX_COMPLETE (SERIAL3_TX_COMPLETE)
#endif
//
// System configuration.  This is used to enable or disable transmission of various
// messages depending on the nodes configuration.  In some cases (i.e. discretes or
// analogs), additional code will need to be added to process the inputs and produce
// the outputs.
//
// Configuration values.  These need to be set individually for each node.
//   name is a fixed lenght string giving the unit name
//   has_discretes set true if discrete values are transmitted
//   has_analogs set true if analog values are transmitted
//   num_analogs set to the number of analog values to transmit
//   has_sonar set to true if PING sonar unit is installed (currently unimplemented)
//
// Select the DEVICE_ID to build software for
//
#define DEVICE_ID 4
//
// Set fixed part of configuration based on the DEVICE_ID
//
// Name must be 32 characters padded with spaces on the end.
//                  12345678901234567890123456789012
#if DEVICE_ID == 1
  const char* name = "Bedroom Sensor Unit             "; // 1
  const bool has_discretes = false;
  const bool has_analogs = false;
  const uint8_t num_analogs = 0;
  const bool has_sonar = false;
#else
#if DEVICE_ID == 2
  const char* name = "Hall Monitor Unit               "; // 2
  const bool has_discretes = false;
  const bool has_analogs = false;
  const uint8_t num_analogs = 0;
  const bool has_sonar = false;
#else
#if DEVICE_ID == 3
  const char* name = "Office Sensor Unit              "; // 3
  const bool has_discretes = false;
  const bool has_analogs = false;
  const uint8_t num_analogs = 0;
  const bool has_sonar = false;
#else
#if DEVICE_ID == 4
  const char* name = "Development and Test Unit PWM   "; // 4
  const bool has_discretes = true;
  const bool has_analogs = true;
  const uint8_t num_analogs = 3;
  const bool has_sonar = false;
#else
#if DEVICE_ID == 5
  const char* name = "Guest Room Sensor Unit          "; // 5
  const bool has_discretes = false;
  const bool has_analogs = false;
  const uint8_t num_analogs = 0;
  const bool has_sonar = false;
#else
#if DEVICE_ID == 6
  const char* name = "Another Sensor Unit             "; // 6
  const bool has_discretes = false;
  const bool has_analogs = false;
  const uint8_t num_analogs = 0;
  const bool has_sonar = false;
#else
  const char* name = "Unknown Sensor Unit             "; // Other ID
  const bool has_discretes = false;
  const bool has_analogs = false;
  const uint8_t num_analogs = 0;
  const bool has_sonar = false;
#endif
#endif
#endif
#endif
#endif
#endif
//
// Check for the presence of I2C based sensors.  These are set during the I2C
// initialization.  Since these are autodetected, they do not need to be specified
// based on DEVICE_ID.
//
extern bool found_BME280;
extern bool found_TSL2561;
extern bool found_CCS811;
extern bool found_PCA9685;
//
// Configuration constants.  When this list gets updated, the determine_transmission
// and determine_config functions also needs to be updated.
//
const uint8_t CONFIG_NAK      = 0; // No configuration item
const uint8_t CONFIG_DISCRETE = 1; // Discretes item
const uint8_t CONFIG_ANALOG   = 2; // Analog item
const uint8_t CONFIG_BME280   = 3; // BME280 environment sensor
const uint8_t CONFIG_TSL2561  = 4; // TSL2561 light sensor
const uint8_t CONFIG_CCS811   = 5; // CCS811 air quality sensor
const uint8_t CONFIG_PCA9685  = 6; // PCA9685 16 channel 12 bit PWM controller

const uint8_t NUM_CONFIG = 7; // Number of configuration items
//
// Configuration array
//
uint8_t config_array[NUM_CONFIG];
//
// Build configuration array
//
uint8_t determine_config();
//
// Determine what to transmit
//
void determine_transmission(uint8_t value);
//
// This can be changed to whatever pin is being used.
//
const uint8_t TX_RX = 5; // Pin 5 is used to control direction.
//
// Routines to transmit I2C data
//
extern void send_BME280(HardwareSerial *);
extern void send_TSL2561(HardwareSerial *);
extern void send_CCS811(HardwareSerial *);
extern void send_PCA9685(HardwareSerial *);
//
extern uint8_t PCA9685_set_chan(uint8_t chan, uint16_t on, uint16_t off);

//
// Sample discrete value
//
uint32_t silly_counter = 0;
//
// Declare functions.
//
//
extern void i2c_init();
extern void i2c_state_machine();
//
// Do whatever local initialization is needed, then call the i2c initializatio
// function.  This will initialize the I2C bus and all the known devices on it.
//
void setup()
{
#if !defined (__AVR_ATmega328P__)
    Serial.begin(BAUD_RATE);
#endif
  rs485->begin(BAUD_RATE);
  if (DEBUG)
  {
    Serial.println(F("Starting initialization."));
    Serial.println(name);
  }
#if DEVICE_ID == 4
  analogReference(DEFAULT);
  pinMode(8, INPUT_PULLUP);
  pinMode(9, INPUT_PULLUP);
  pinMode(10, INPUT_PULLUP);
  pinMode(11, INPUT_PULLUP);
#endif
  pinMode(TX_RX, OUTPUT);
  pinMode(LED_BUILTIN, OUTPUT);
  digitalWrite(TX_RX, LOW);
  digitalWrite(LED_BUILTIN, LOW);
  i2c_init();
  if (DEBUG)
  {
    Serial.println(F("Initialization complete.  Waiting for data."));
  }
  determine_config();
}
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

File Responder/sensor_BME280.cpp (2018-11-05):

#include <RS-485.h>
#include <wiring_private.h>
#include <Wire.h>

static const bool DEBUG = false;
//
// I2C Stuff
//
const uint32_t I2C_TIMEOUT = 500;
extern uint8_t i2c_buffer[BUFFER_SIZE];
extern uint8_t buff_ptr;
extern uint8_t bytes_pending;
extern uint32_t end_time;
//
extern uint8_t i2c_start_read(uint8_t device, uint8_t reg, uint8_t bytes);
extern uint8_t i2c_read_pending();
//
extern bool found_BME280;
//
// Status for sub-state machines
//
static const uint8_t MACHINE_WORKING = 1;
static const uint8_t MACHINE_DONE = 2;
//
static const uint8_t STATE_BME280_START_CONVERSION = 1;
static const uint8_t STATE_BME280_ASK_DATA_READY = 2;
static const uint8_t STATE_BME280_CHECK_DATA_READY = 3;
static const uint8_t STATE_BME280_START_READ = 4;
static const uint8_t STATE_BME280_CHECK_READ = 5;
static const uint8_t STATE_BME280_END_READ = 6;
static const uint8_t STATE_BME280_PROCESS1 = 7;  // Split into three steps to avoid too much time in each loop
static const uint8_t STATE_BME280_PROCESS2 = 8;
static const uint8_t STATE_BME280_PROCESS3 = 9;
//
static uint8_t BME280_state = STATE_BME280_START_CONVERSION;
//
// Calibration values for BME280
//
static uint16_t BME280_cal_T1 = 0;
static int16_t BME280_cal_T2 = 0;
static int16_t BME280_cal_T3 = 0;
static uint16_t BME280_cal_P1 = 0;
static int16_t BME280_cal_P2 = 0;
static int16_t BME280_cal_P3 = 0;
static int16_t BME280_cal_P4 = 0;
static int16_t BME280_cal_P5 = 0;
static int16_t BME280_cal_P6 = 0;
static int16_t BME280_cal_P7 = 0;
static int16_t BME280_cal_P8 = 0;
static int16_t BME280_cal_P9 = 0;
static uint8_t BME280_cal_H1 = 0;
static int16_t BME280_cal_H2 = 0;
static uint8_t BME280_cal_H3 = 0;
static int16_t BME280_cal_H4 = 0;
static int16_t BME280_cal_H5 = 0;
static uint8_t BME280_cal_H6 = 0;
//
// Sensor values for BME280
//
static uint8_t BME280_status = DATA_INIT;
static uint8_t BME280_age = 0;
static uint32_t raw_press;
static uint32_t raw_temp;
static uint32_t raw_hum;
static int32_t  t_fine;    // Calibrated temperature
static uint32_t cal_press; // Calibrated pressure (Pa/256)
static uint32_t cal_hum;   // Calibrated humidity (%/1024)
//
// BME280 Constant values
//
static const uint8_t ADDR_BME280 = 0x77;
//
// Registers
//
static const uint8_t BME280_CTRL_HUM = 0xF2;
static const uint8_t BME280_STATUS = 0xF3;
static const uint8_t BME280_CTRL_MEAS = 0xF4;
static const uint8_t BME280_CONFIG = 0xF5;
static const uint8_t BME280_DATA_START = 0xF7;
static const uint8_t BME280_RESET = 0xE0;
static const uint8_t BME280_ID_ADDR = 0xD0;
//
// Register values
//
static const uint8_t BME280_MODE_SLEEP = 0x00;
static const uint8_t BME280_MODE_FORCE = 0x02;
static const uint8_t BME280_MODE_NORMAL = 0x03;
static const uint8_t BME280_HUM_OVER_1 =  0x01;
static const uint8_t BME280_PRESS_OVER_1 = 0x20;
static const uint8_t BME280_TEMP_OVER_1 = 0x04;
static const uint8_t BME280_ID_VALUE = 0x60;
//
// Status values
//
static const uint8_t BME280_STAT_MEASURING = 0x08;
static const uint8_t BME280_STAT_IM_UPDATE = 0x01;
//
// Local function definitions
//
static void BME280_get_raw_values();
static int32_t BME280_cal_temp();
static uint32_t BME280_cal_press();
static uint32_t BME280_cal_hum();
//
static void BME280_start_conversion()
{
  Wire.beginTransmission(ADDR_BME280);
  Wire.write(BME280_CTRL_MEAS);
  Wire.write(BME280_MODE_FORCE + BME280_TEMP_OVER_1 + BME280_PRESS_OVER_1);
}

static void BME280_request_ID()
{
  i2c_start_read(ADDR_BME280, BME280_ID_ADDR, 1);
}

static void BME280_request_status()
{
  i2c_start_read(ADDR_BME280, BME280_STATUS, 1);
}

static void BME280_request_data()
{
  i2c_start_read(ADDR_BME280, BME280_DATA_START, 8);
}

static bool BME280_check_data_ready()
{
  return ((i2c_buffer[0] & BME280_STAT_MEASURING) == BME280_STAT_MEASURING);
}

void send_BME280(HardwareSerial *rs485)
{
  rs485->print("#");
  rs485->print(device, HEX);
  rs485->print("/");
  rs485->print(address, HEX);
  rs485->print("/");
  rs485->print(MSG_TYPE_BME280, HEX);
  rs485->print("&");
  rs485->print(BME280_status, HEX);
  rs485->print("&");
  rs485->print(BME280_age, HEX);
  rs485->print("&");
  rs485->print(t_fine, HEX);
  rs485->print("&");
  rs485->print(cal_press, HEX);
  rs485->print("&");
  rs485->print(cal_hum, HEX);
  rs485->println("%FF");
  BME280_status = DATA_STALE;
  BME280_age++;
}
//
// Functions for BME280 sensor.  This code is based on some Ada code that I wrote that was based
// on some C code from the data sheet.
//
void BME280_init()
{
  //
  // Check if BME280 is present
  //
  BME280_request_ID();
  if (DEBUG)
  {
    Serial.println(F("Waiting for BME280 to respond."));
  }
  end_time = millis() + I2C_TIMEOUT; // Compute timeout value
  while ((i2c_read_pending() > 0) && (millis() > end_time));
  if (i2c_buffer[0] != BME280_ID_VALUE)
  {
    if (DEBUG)
    {
      Serial.println(F("Unable to find BME280."));
      Serial.print(F("Found ID "));
      Serial.println(i2c_buffer[0], HEX);
    }
    BME280_status = DATA_SENSOR;
  }
  else
  {
    found_BME280 = true;
    if (DEBUG)
    {
      Serial.println(F("BME280 Found."));
    }
  }
  //
  // No point continuing if the device was not found.
  //
  if (!found_BME280)
  {
    return;
  }
  //
  // Read calibration constants;
  //
  i2c_start_read(ADDR_BME280, 0x88, 24);
  while (i2c_read_pending() > 0);
  BME280_cal_T1 = i2c_buffer[0] + (i2c_buffer[1] << 8);
  BME280_cal_T2 = i2c_buffer[2] + (i2c_buffer[3] << 8);
  BME280_cal_T3 = i2c_buffer[4] + (i2c_buffer[5] << 8);
  BME280_cal_P1 = i2c_buffer[6] + (i2c_buffer[7] << 8);
  BME280_cal_P2 = i2c_buffer[8] + (i2c_buffer[9] << 8);
  BME280_cal_P3 = i2c_buffer[10] + (i2c_buffer[11] << 8);
  BME280_cal_P4 = i2c_buffer[12] + (i2c_buffer[13] << 8);
  BME280_cal_P5 = i2c_buffer[14] + (i2c_buffer[15] << 8);
  BME280_cal_P6 = i2c_buffer[16] + (i2c_buffer[17] << 8);
  BME280_cal_P7 = i2c_buffer[18] + (i2c_buffer[19] << 8);
  BME280_cal_P8 = i2c_buffer[20] + (i2c_buffer[21] << 8);
  BME280_cal_P9 = i2c_buffer[22] + (i2c_buffer[23] << 8);
  i2c_start_read(ADDR_BME280, 0xA1, 1);
  while (i2c_read_pending() > 0);
  BME280_cal_H1 = i2c_buffer[0];
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

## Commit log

2018-08-14 Initial load of software
    Load existing software into repository to start version control.
    [config.txt]
2018-08-14 Start working on web server
    The web server builds and runs on the BeagleBone Black. Updates include:
    * Add Web/init-bbb.sh
    Shell script to configure BeagleBone Black I/O
    * Add Web/src/rs485.adb
    * Contains body of RS485 task. Initial version just reads and prints.
    * Add Web/src/rs485.ads
    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
2018-08-17 Data is read from the RS-485 bus, saved, and provided by the web server.
    New files added:
    init-bbb.sh - Configure the system. Needs to be run once after the system
    is booted and before running the web program.
    rs485.ads & rs485.adb - Read the RS-485 bus and extract data.
    Modifications to other files support presentation of data.
    [config.txt]
2018-08-20 Start work on creating a dashboard to display sensor values.
    The web server now provides XML data from the sensors that can be queried by
    JavaScript. The presentation can now be controlled by the HTML, CSS, and
    JavaScript files. In the process, a bug in the svg thermometer code was
    discovered and corrected. This needs to also be pushed to the generic web
    server repository.
    [config.txt]
2018-08-26 Update to pull in latest updates from Ada-Web-Server
    Pull in updates from Ada-Web-Server to allow the configuration file to be
    reloaded without needing to restart the program.
    Pull in update to add a counter for the number of currently active tasks.
    [config.txt]
2018-08-29 Change handler task system
    The original system with the handler tasks being detached and left to run to
    completion after being started did not work as a long term solution. It
    appears that the tasks were not being cleaned up by the run time system. This
    led to a memory leak. The new system creates a limited number of tasks to
    start with and then allocates work to them on a round-robin basis. This seems
    to have cured the memory leak.
    [config.txt]
2018-08-30 Make RS-485 data protected and prepare to send commands
    The RS-485 data store have been converted to a protected type to help avoid
    any problems when trying to read the data at the same time as the state
    machine task is writing data.
    Add code to transmit text on the RS-485 port. This will be used to send
    commands to the controller Arduino. Note that send data goes on an
    entirely different internal RS-485 bus and is not read by any of the other
    devices on the RS-485 network.
    [config.txt]
2018-08-31 Update controller to receive commands
    The Arduino controller software is updated to receive and respond to commands
    from the BeagleBone Black. Currently only 4 commands are supported as a proof
    of concept.
2018-08-31 Minor updates to setting.html and test1.js
    Update the settings page to remove some test stuff and add buttons and code
    to send commands to the network controller.
2018-09-04 Updates to support debugging
    Updates to the settings page and a number of Ada files to enable various
    debugging messages to be turned on and off without recompiling the program.
    Supported messages are:
    RS485 character data from the bus.
    RS485 messages from the bus.
    HTTP requests.
    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
    [config.txt]
2018-09-06 Bug fix and work on settings
    Fixed a bug where requesting a configuration update would never work.
    Changed test1.js to settings.js to slowly move a way from the more
    experimental approach to some sensible naming.
    The settings page now shows the counter values when it is loaded.
    [config.txt]
2018-09-19 I got tired of having to make changes in two places every time I updated the web server code. So things have been decoupled. All the common web server code is now in Ada-Web-Server and it is a depend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
2018-10-05 Documentation Updates
    Create a set of basic wiring/connection diagrams for the nodes and add them to the documentation. The generating KiCAD files may be added later.
2018-10-10 Add Schematics
    1. Minor documentation update to include updated wiring diagram.
    2. Add KiCAD schematics to produce the wiring diagrams.
    [Arduino-Sensors.sch, Basic Responder.sch, Controller.sch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]
2018-10-23 Modify Arduino Responder software to consolodate per unit configuration definitions.
2018-10-24 Start working on state machine to support directed commands from network controller. Add utility routine to perform a software reset (jmp 0).
    [RS-485.h, Responder.ino]
2018-10-28 Documentation Updates
    Update documentation
    1. Hardware doc updated to better show pull up and pull down resistors on RS-485 bus.
    2. System Overview updated to extend request messages to include commands. Also add analogs to responses.
2018-10-31 Updates to Arduino controller to begin support for directed commands. Currently the only directed command supported is reset to node 4.
    [Controller.ino, Responder.ino]
2018-11-01 Update controller software to support directed commands reset and send arbitrary command to any node (>0) on the network.
    [Controller.ino]
2018-11-02 RS485 changes: 1. Update state machine parser to recognize directed commands 2. Restructure device message database 3. Update dashboard to indicate in the device list which devices are stale.
2018-11-05 Updates to support PCA9685 16-channel, 12-bit PWM controller. Software is not yet tested, but doesn't seem to cause problems when no PCA9685 is connected.
    [PCA9685.cpp, RS-485.h, Responder.ino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]
2018-11-06 More updates to support PCA9685 on Arduino.
2018-11-06 Initial changes to web intereface to support PCA9685 PWM controller.
2018-11-09 Updates to enable logging of RS-485 data to files. Currently only logging of information and BME280 messages to CSV files is supported, but this can now be easily expanded. The logging can also now b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
    [config.txt]
2018-11-11 More logging updates to log all data from currently defined I2C sensors. The analogs and discretes are a little too custom for general purpose logging. Specific logging for these would need to be wri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
    Update .gitignore to ignore *.csv files generated by logging and .DS_Store
    files.
2018-11-20 Documentation Updates
    Update system overview to include:
    1. Current back-channel commands
    2. Logging
    3. Web API
2018-11-25 Minor update to arduino responder software to send a MSG_TYPE_EMPTY to acknowlege a write command.
2023-06-15 Convert schematics to KiCad v7.
    [Arduino-Sensors-2023-06-14-08-46-27.sch, Arduino-Sensors.kicad_sch, Basic Responder-2023-06-14-08-46-27.sch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]
